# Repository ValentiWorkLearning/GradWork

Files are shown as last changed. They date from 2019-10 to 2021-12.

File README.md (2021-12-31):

# GradWork


Development board for smart-handwatch based on NRF52832 E73 module with C++20/CMake/VSCode based development flow

* Uses the C++20 features as wide as possible
* Uses С++20 coroutines for non-blocking interactions
* Port of LVGL 8.0 library for ST7789V/GC9A01 display and NRFSDK
* Simulator for fimware development without target MCU
* CI for Windows Simulator build and GCC build for target

### Article:
[C++20 Coroutines on NRF52832 with GTest](https://habr.com/ru/post/566070/)

### Revision v1.2
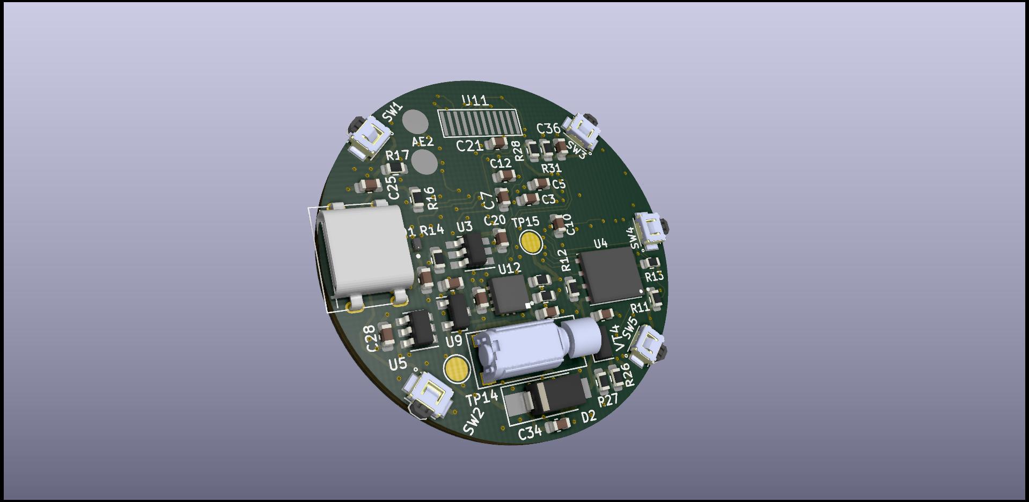
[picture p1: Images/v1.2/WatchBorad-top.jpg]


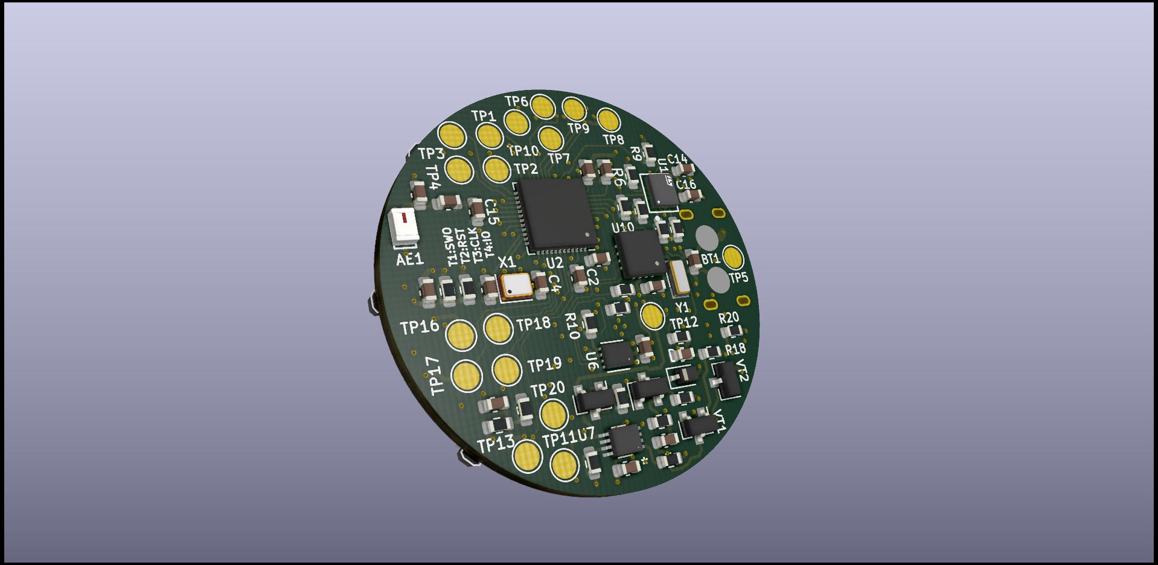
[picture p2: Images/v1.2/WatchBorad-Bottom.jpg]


### Revision v1.0
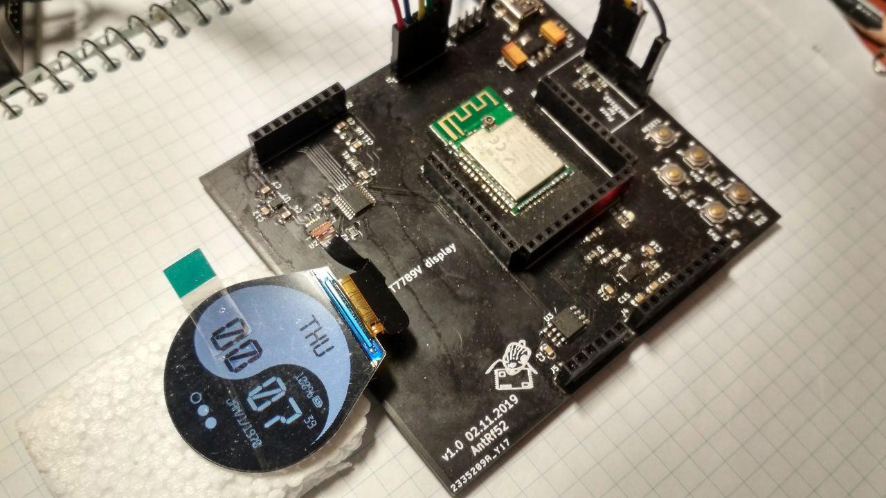
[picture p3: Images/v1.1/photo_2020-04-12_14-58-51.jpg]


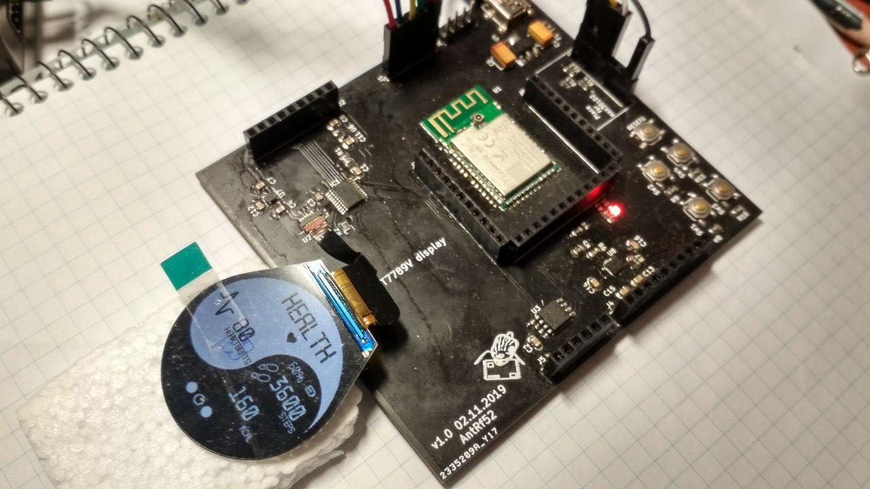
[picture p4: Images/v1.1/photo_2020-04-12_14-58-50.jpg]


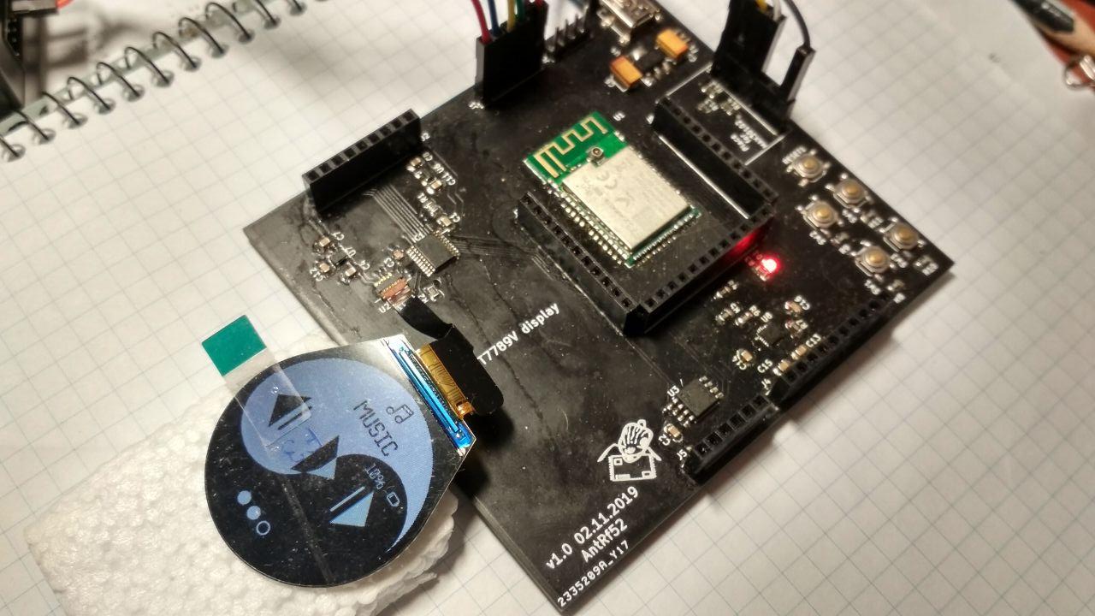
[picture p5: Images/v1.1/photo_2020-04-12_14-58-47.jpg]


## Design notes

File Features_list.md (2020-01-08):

## **Round watch development board  summary **

###### Hardware features:

- [ ] Pulse and SPO2 measuring

- [x] Integration with ST7789V display driver

- [x] LVGL library porting

- [x] BLE custom service

- [ ] Time displaying ( RTC )

- [ ] Time synchronization over BLE Service

- [x] Battery level displaying BLE

- [ ] Battery level displaying Display

- [ ] Accelerometer clock sleep out

- [ ] Energy-Save mode

  ###### Android integration:

- [ ] Alarms support

- [ ] Notifications from Android device

- [ ] Music switching over Android device

  ###### Optional / Additional features

- [ ] Simple 3D render engine for triangles wireframe rendering

- [ ] Mobile application

- [x] CMake-based  build for project

- [x] VSCode debug & development

- [x] KiCad as CAD system for PCB

- [ ] I2S micro for audiomessages

- [ ] Research lightweight inter-processor communication

## **Part list:**

### **MCU:**

NRF52832-E73 module

#### **Accelerometer:**

MPU9250

#### Display module:

ST7789V Round, resolution 240 * 240 or 240 * 208

https://github.com/ValentiWorkLearning/ST7789_Round_DevBoard/tree/master/Panel

https://ru.aliexpress.com/item/1962405888.html?spm=a2g0o.cart.0.0.38713c00M67wvz&mp=1

#### PulseOximeter:

MAX30102/MAX30100

http://www.kosmodrom.com.ua/el.php?name=MAX30100-MODUL

#### **Logic converter:**

TX0108E

http://www.kosmodrom.com.ua/el.php?name=TXS0108EPWR

**Battery controller:**

LTC4054ES5-4.2

http://www.kosmodrom.com.ua/el.php?name=LTC4054ES5-4.2

**LDO**

1. 1.8V - MCP1700T-1802 http://www.kosmodrom.com.ua/el.php?name=MCP1700T-1802E_MB
2. 3.3V - MCP1700T-3302 http://www.kosmodrom.com.ua/el.php?name=MCP1700T-3302E_TT
3. 2.8V - LP2985 http://www.kosmodrom.com.ua/el.php?name=LP2985AIM5-2.8_NOPB

#### Schematic Libraries:

- Nordic nRF52832 MOD

https://kicad.github.io/symbols/RF_Module

- W25Q128

[https://www.snapeda.com/parts/W25Q16BVSSIG/Winbond%20Electronics/view-part/](https://www.snapeda.com/parts/W25Q16BVSSIG/Winbond Electronics/view-part/) 

- MPU-9250

[https://www.snapeda.com/parts/MPU-9250/TDK%20InvenSense/view-part/](https://www.snapeda.com/parts/MPU-9250/TDK InvenSense/view-part/)

#### Software dependencies:

* LVGL - https://github.com/littlevgl/lvgl - open-source embedded GUI library
* Callback connector - library for wrapping C++ class members into C-style callback 

https://github.com/Toxa-man/CallbackConnector 

* Lightweight C++ signals for small systems  https://github.com/larspensjo/SimpleSignal
* SDL-mirror - is used by Simulator subproject https://github.com/spurious/SDL-mirror

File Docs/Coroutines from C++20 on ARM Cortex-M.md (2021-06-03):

### Coroutines from C++20 on ARM Cortex-M

Подробные пояснения по сопрограммам, их особенностям реализации, преимуществами, примерами использования можно посмотреть в следующем списке статей. Ознакомление с статьями рекомендую в следующем порядке:

https://www.youtube.com/watch?v=Ts-1mWBmTNE - MUST WATCH видео от автора предложения Coroutines в стандарт С++20. Раскрыты детали реализации сопрограмм, бенчмарки в сравнении с "callback hell". Рекомендуется к просмотру в первую очередь.

https://blog.panicsoftware.com/coroutines-introduction/ - тут хорошая начальная теория. Либо, взять за основу следующую статью:

https://luncliff.github.io/posts/Exploring-MSVC-Coroutine.html - тут больше картинок и примеры кода есть под конец статьи

https://blog.panicsoftware.com/your-first-coroutine/ - следующая в цикле статей, для начального понимания происходящего

https://lewissbaker.github.io/2017/09/25/coroutine-theory - базовая теория по сопрограммам, для начала может быть сложной

https://habr.com/ru/company/yandex/blog/420861/ - полезный пример "телепортации" между различными очередями задач

https://habr.com/en/post/348602/ - как использовать сопрограммы из С++20 в связке с boost::asio

 https://habr.com/en/post/493808/ // coroutine code linearizing - Линеаризация кода с использованием сопрограмм. Показаны фрагменты реализации модели Акторов.

https://manybutfinite.com/post/anatomy-of-a-program-in-memory/ 

https://manybutfinite.com/post/journey-to-the-stack/

В свою очередь, было решено попробовать фишки из С++20 в домашнем проекте. Прежде, чем собирать все в реальном проекте -  был сделан отдельный репозиторий https://github.com/ValentiWorkLearning/CoroutineExperiments/ . В репозитории была реализована первая идея- использовать сопрограммы для переписывания драйвера для дисплея, работающего по SPI. 

### Пояснение демонстрационного примера из репозитория CoroutineExperiments

Для реализации "эмуляции" передачи данных по интерфейсу SPI  с использованием DMA необходимо реализовать следующий набор функций:

* Сигнатуру HAL(Hardware Abstraction Layer) подобную доступной в API конкретного вендора.
* Пользовательскую сигнатуру для передачи данных( например, передачи команды на дисплей)
* Функцию инициализации дисплея

API для передачи данных, в большинстве своем, имеют похожий вид-указатель на блок данных + размер передаваемого блока + void* на _pUserData -подобный "контекст". Так-же, имеется функционал для инициализации интерфейса.

В случае Nordic, например, сигнатура функции для инициализации SPI имеет вид:

```cpp
nrfx_err_t nrfx_spim_init(nrfx_spim_t  const * const p_instance,
                          nrfx_spim_config_t const * p_config,
                          nrfx_spim_evt_handler_t    handler,
                          void                     * p_context)
```

где p_context- "контекст" который будет доступен в `nrfx_spim_evt_handler_t    handler` callback-е.

Инициализация интерфейса SPI происходит вызовом nrfx_spim_init:

```cpp
APP_ERROR_CHECK(
    nrfx_spim_init(&m_spiHandle, &spiConfig, spimEventHandler, this));
```

Аргументами которой являются:

* m_spiHandle- структура-дескриптор, которая выглядит следующим образом:

  ```cpp
  typedef struct
  {
      NRF_SPIM_Type * p_reg;        ///< Pointer to a structure with SPIM registers.
      uint8_t         drv_inst_idx; ///< Index of the driver instance. For internal use only.
  } nrfx_spim_t;
  ```

* spiConfig- структура с конфигурацией SPI( скорость, используемые порты, etc). Подробнее фрагмент можно посмотреть [ссылка на листинг в репозитории](https://github.com/ValentiWorkLearning/GradWork/blob/9262f65599d58640db2a972ff668a8b065b6441c/Firmware/drivers/spi/spi_wrapper.cpp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)

* spimEventHandler- callback, вызываемый в момент обработки события на шине SPI, по завершению приема/передачи.

* this- контекст, который будет доступен в обработчике события, в текущей реализации-обрабатывает состояние транзакций на шине.

Callback реализован как:

```cpp
static void spimEventHandler(nrfx_spim_evt_t const* _pEvent,
                             void* _pContext) noexcept {
  Meta::UnuseVar(_pContext);
  if (_pEvent->type == NRFX_SPIM_EVENT_DONE) {
    auto pThis = reinterpret_cast<SpiBus::SpiBackendImpl*>(_pContext);
    pThis->m_pSpiBus->handleEvent(
        SpiBus::TCompletedEvent::TransactionCompleted);
  }
}
```

Передача данных по SPI формируется созданием дескриптора транзакции + инициации передачи данных:

```cpp
nrfx_spim_xfer_desc_t xferDesc = NRFX_SPIM_XFER_TX(_pBuffer, _bufferSize);
nrfx_err_t transmissionError = nrfx_spim_xfer
        &m_spiHandle
    ,   &xferDesc
    ,   0
);
```

В общем случае,  можно объединить вызов в :

```cpp
void sendDataChunk(std::uint8_t* _pData,
                   std::uint16_t _dataSize,
                   void* _pUserContext);
```

При необходимости передачи данных блоком, например-  передачи блока команд инициализации на дисплей в неблокирующем режиме - в традиционном варианте необходимо сформировать очередь на отправку, из которой по прерыванию(событию?) доставать новый блок данных и формировать пакет на отправку.

В коде выглядит примерно как:

```cpp
sendCommand(DisplayReg::SLPOUT);
sendCommand(DisplayReg::COLMOD, 0x55);
sendCommand(DisplayReg::MADCTL, 0x08);
```

Реализацию sendCommand можно посмотреть [тут](https://github.com/ValentiWorkLearning/GradWork/blob/9262f65599d58640db2a972ff668a8b065b6441c/Firmware/drivers/display/inc/display/display_spi_common.hpp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)

Вкратце- помещаем в очередь выполнения SPI - транзакцию с beforeTransaction, transactionAction,afterTransaction.

### CoroutineExperiments implementation

В предыдущем разделе был упомянут "объединенный" вызов для запуска передачи данных. Для эмуляции асинхронной передачи данных реализуем HAL-метод следующий образом:

- P.S. восстановление сопрограммы происходит не в потоке, откуда была инициирована передача данных, если это является проблемой- возможно использовать подход, описанный в [Готовимся к С++20. Coroutines TS на реальном примере](https://habr.com/ru/company/yandex/blog/420861/) или [Асинхронность 2: телепортация сквозь порталы](https://habr.com/ru/company/yandex/blog/240525/)

```cpp
void spiBackendImplTransmit(std::uint8_t* _pBuffer,
                            std::uint16_t _bufferSize,
                            void* _pUserData) {
  std::thread dmaThread = std::thread([_pUserData] {
    using namespace std::chrono_literals;
    std::this_thread::sleep_for(500ms);

    std::cout << "TRANSMIT SOME DATA" << std::endl;
    stdcoro::coroutine_handle<>::from_address(_pUserData).resume();
  });
  dmaThread.detach();
}
```

Пользовательский метод передачи данных реализуем следующим образом

```cpp
auto spiTrasnmitCommandBufferAsync(std::uint8_t* _pBuffer,
                                   std::uint16_t _bufferSize) {
  std::cout << "Toggle GPIO ON" << std::endl;
  struct Awaiter {
    std::uint8_t* pBuffer;
    std::uint16_t bufferSize;

    bool await_ready() const noexcept { return false; }
    void await_resume() const noexcept {
      std::cout << "Toggle GPIO OFF" << std::endl;
    }
    void await_suspend(stdcoro::coroutine_handle<> thisCoroutine) const {
      spiBackendImplTransmit(pBuffer, bufferSize, thisCoroutine.address());
    }
  };

  return Awaiter{.pBuffer = _pBuffer, .bufferSize = _bufferSize};
}
```

`bool await_ready() const noexcept` - возвращает всегда false, т.к. нам гарантированно надо выполнять операцию для получения результата awaitable.

`void await_resume() const noexcept` - момент "восстановления" сопрограммы

`void await_suspend(stdcoro::coroutine_handle<> thisCoroutine) const` - функция, вызываемая в момент приостановки сопрограммы

И получим следующую реализацию функции инициализации дисплея:

```cpp
auto commandBufferFirst = std::array{0x00u, 0x01u, 0x02u, 0x03u};
auto commandBufferSecond = std::array{0x04u, 0x05u, 0x06u, 0x07u, 0x08u};

void initDisplay() {
  co_await spiTrasnmitCommandBufferAsync(
      reinterpret_cast<std::uint8_t*>(commandBufferFirst.data()),
      commandBufferFirst.size());
  co_await spiTrasnmitCommandBufferAsync(
      reinterpret_cast<std::uint8_t*>(commandBufferSecond.data()),
      commandBufferSecond.size());
}
```

Подробный полный пример доступен [Ссылка на репозиторий](https://github.com/ValentiWorkLearning/CoroutineExperiments/)

### Мигаем светодиодом на NRF52832

Имея механизм сопрограмм, и исследовав пример [Exploring MSVC Coroutine](https://luncliff.github.io/posts/Exploring-MSVC-Coroutine.html)

мы можем помигать светодиодом с весьма интересным синтаксисом:

```cpp

void Board::ledToggle() {
  using namespace std::chrono_literals;
  while (true) {
    co_await 300ms;

    LOG_DEBUG_ENDL("LED TIMER EXPIRED");
    bsp_board_led_invert(0);
  }
}

```

Немного освежив в памяти API FreeRTOS - вспоминается следующий фрагмент кода:

```cpp
xTaskCreate(ledBlinkTask, "ledBlinkTask", 128, NULL, 2, NULL);

void ledBlinkTask(void* pvParameters) {
  while (true) {
    vTaskDelay(300 / portTICK_PERIOD_MS);
    bsp_board_led_invert(0);
  }
}
```

Реализация `co_await 300ms` схожа с вышеупомянутой статьей с [Exploring MSVC Coroutine](https://luncliff.github.io/posts/Exploring-MSVC-Coroutine.html), а именно следующая:

```cpp
auto operator co_await(std::chrono::milliseconds _duration) {
  class Awaitable {
   public:
    explicit Awaitable(std::chrono::milliseconds _duration)
        : m_duration{_duration} {}

    bool await_ready() const { return false; }

    void await_suspend(std::coroutine_handle<> _coroLedHandle) {
      ret_code_t errorCode{};
      errorCode =
          app_timer_start(m_ledDriverTimer, APP_TIMER_TICKS(m_duration.count()),
                          _coroLedHandle.address());
      APP_ERROR_CHECK(errorCode);
    }

    void await_resume() { app_timer_stop(m_ledDriverTimer); }

   private:
    std::chrono::milliseconds m_duration;
  };
  return Awaitable{_duration};
}
```

Где на `await_suspend` сопрограммы делается запуск таймера на заданный период(`300ms`),  в обработчике таймера вызывается `coroutine_handle.resume()` , после которого таймер останавливается в `void await_resume()`. 

Полная реализация доступна [Ссылка на репозиторий,watchboard.cpp](https://github.com/ValentiWorkLearning/GradWork/blob/dev/develop/Firmware/drivers/board/watchboard.cpp)

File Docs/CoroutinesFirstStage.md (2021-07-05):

### Practical C++20 coroutines notes for ARM Cortex-M

Появилась идея в домашнем проекте попробовать использовать сопрограммы из С++20 на маленькой железке. В качестве модуля для экспериментов был выбран E73 NRF52832. Из инструментария, который использовался в процессе разработки- arm-gcc-gnu-none-eabi 10.2, MSVC для проверки идей и прогона тестов на Windows-платформе.
Изначально было в планах продемонстрировать на чем-то концепцию и как именно их можно было применять. Была идея адаптирования примера в виде мигания светодиодом, но он был слишком простой. Необходимо было придумать что-то более сложное и более полезное, что ли. Таким образом появилась идея переписать драйвер дисплея и пары фрагментов SPI-FLASH в проекте-долгострое.

Небольшой план, что будет в заметке:

1. Предыстория с транзакциями
2. Как это работает в общих чертах
3. Работаем с SPI интерфейсом
4. Массив команд инициализации
5. Идеи с std::tuple транзакций
6. Реализуем when_all_sequence
7. Как работает Task из cppcoro
8. Как это тестировать?
9. Добавляем параметрические тесты в GTest
10. Добавляем черновой вариант драйвера для SPI-FLASH
11. Добавляем чтение JEDEC ID
12. Добавляем чтение device id
13. Ожидание окончания выполнения сопрограммы

### 0. Перед прочтением
Заметка предполагает базовое знакомство читателя с сопрограммами/их синтаксисом. В силу наличия более подробных статей на тему деталей реализации сопрограмм и их устройства рекомендуются к прочтению следующие материалы:

* [YOUR FIRST COROUTINE,panicsoftware](https://blog.panicsoftware.com/your-first-coroutine/)

Серия статей от автора библиотеки [cppcoro](https://github.com/lewissbaker/cppcoro)
* https://lewissbaker.github.io/2017/09/25/coroutine-theory
* https://lewissbaker.github.io/2017/11/17/understanding-operator-co-await
* https://lewissbaker.github.io/2018/09/05/understanding-the-promise-type
* https://lewissbaker.github.io/2020/05/11/understanding_symmetric_transfer

В заметке изложение материала может показаться непоследовательным. Предложения буду рад увидеть в виде issues или же в комментариях/сообщениях в Telegram.

Что будет рассмотрено:
* драйвер дисплея с использованием сопрограмм, с использованием таблицы инициализации на базе std::tuple и классического варианта на базе массива команд.
* фрагмент драйвера для SPI-FLASH памяти
* написание тестов на драйвер SPI с использованием параметрических тестов в GTest
* Рассмотрение работы и реализация нескольких примитивов из cppcoro библиотеки.

### 1. Предыстория с транзакциями

Изначально идея переписывания с подхода в виде транзакций появилась как только возникла необходимость расширения транзакционности read-транзакциями. Для формирования очереди отправки этот подход был достаточно удобным, но для очереди приема получалось что-то вроде callback-hell подхода.

В общих чертах, транзакционный подход представлял собой следующую идею:
```cpp
template <typename... Args> void sendCommand(std::uint8_t command, Args... commandArgs) noexcept
{
    sendCommand(command);
    sendChunk(static_cast<std::uint8_t>(commandArgs)...);
}

template <typename... Args> void sendChunk(Args... _chunkArgs) noexcept
{
    std::array chunk = {static_cast<std::uint8_t>(_chunkArgs)...};
    Interface::Spi::Transaction chunkTransaction{};

    chunkTransaction.beforeTransaction = [this] { setDcPin(); };

    chunkTransaction.transactionAction = [this, chunkToSend = std::move(chunk)] {
        m_pBusPtr->sendChunk(
            reinterpret_cast<const std::uint8_t*>(chunkToSend.data()), chunkToSend.size());
    };

    chunkTransaction.afterTransaction = [this] { resetDcPin(); };

    m_pBusPtr->addTransaction(std::move(chunkTransaction));
}
```

Т.е. у нас есть некоторое действие до транзакции, сама транзакция и действие, которое будет выполнено после нее. Использование так-же было достаточно удобным:
```cpp
sendCommand(DisplayReg::SLPOUT);
sendCommand(DisplayReg::COLMOD, 0x55);
sendCommand(DisplayReg::MADCTL, 0x08);
sendCommand(DisplayReg::CASET, 0x00, 0, 0, 240);
```
Этот подход достаточно хорошо себя показал в работе. Типовая задача для применения имела следующий вид:

1. Выставить состояние порта D/C для дисплея для выбора типа принимаемых данных (команда или данные);
2. Сформировать DMA- транзакцию;
3. По ее окончанию выполнить следующую отправку, если блок данных был не полностью отправлен;
4. Или вернуть состояние порта D/C в исходное состояние и перейти к обработке следующей транзакции.

Недостатки стали проявляться при попытке реализации драйвера для SPI-FLASH которая должна была быть использована в связке с Little FS. Где-то в тот-же период времени было найдено предложение в стандарт С++20 по сопрограммам, просмотрена серия мотивирующих статей:
* [Готовимся к С++20. Coroutines TS на реальном примере](https://habr.com/ru/company/yandex/blog/420861/)

* [Асинхронность: назад в будущее](https://habr.com/ru/post/201826/)
* [Асинхронность 2: телепортация сквозь порталы](https://habr.com/ru/company/yandex/blog/240525/)
* [Асинхронность 3: Субъекторная модель](https://habr.com/ru/post/340732/)

И было принято решение о переписывании на сопрограммы части существующих драйверов.

### 2. Как это работает в общих чертах
Для разработчиков, которые имели дело с C#/Python/JS не являются чем-то новым ключевые слова `yeild`, `await`,`async`.(Да, они тут приведены в общем варианте, без принадлежности к конкретному языку). В кратце, идея сопрограмм состоит в возможности приостановки функции в любом месте исполнения с последствующим восстановлением ее работы из прерванной точки. Фактически, мы получаем легковесные потоки уровня пользователя, т.е. для переключения сопрограмм нам нет необходимости обращаться к ядру ОС/etc.

В С++20 минимальный пример сопрограммы может быть представлен в виде следущей конструкции:
```cpp
#include <coroutine>
#include <iostream>

struct Awaitable
{
    struct Promise;
    using promise_type = Promise;

    Awaitable(std::coroutine_handle<promise_type> coroHandle) : thisCoroutine{coroHandle}
    {
        std::cout << "Awaitable created\n";
    }
    ~Awaitable()
    {
        std::cout << "Awaitable destroyed\n";
        if (thisCoroutine)
            thisCoroutine.destroy();
    }
    struct Promise
    {
        auto initial_suspend() noexcept
        {
            return std::suspend_always();
        }
        auto final_suspend() noexcept
        {
            return std::suspend_always();
        }
        void unhandled_exception()
        {
            std::terminate();
        }

        Awaitable get_return_object()
        {
            return Awaitable(std::coroutine_handle<promise_type>::from_promise(*this));
        }
        void return_void() noexcept
        {
        }
    };
    bool isFinished()
    {
        if (thisCoroutine)
            return thisCoroutine.done();
        return false;
    }
    void restore()
    {
        if (thisCoroutine && !thisCoroutine.done())
            thisCoroutine.resume();
    }
    std::coroutine_handle<promise_type> thisCoroutine;
};

Awaitable callMe()
{
    std::cout << "Hello ";
    co_await std::suspend_always{};
    std::cout << "World\n";
}
int main()
{
    auto lazyHello = callMe();
    while (!lazyHello.isFinished())
        lazyHello.restore();

    return 0;
}
```
Где полезная нагрузка- ленивый вывод фразы "Hello world".
Попробуем реализовать идею использования, только на примере чего-то реальнее. Например, инициализации и работы с дисплеем. Для интереса, весь обмен должен происходить с использованием DMA микроконтроллера.

### 3. Работа с SPI интерфейсом
 Для работы с SPI интерфейсом необходимо реализовать небольшой набор Awaitable-типов, на которых может быть вызван оператор `co_await`.
Самый простой вариант имеет следующий вид:
```cpp
struct Awaiter
{
    bool resetDcPin = false;
    bool restoreInSpiCtx = false;
    const std::uint8_t* pTransmitBuffer;
    This_t* pBaseDisplay;
    std::uint16_t bufferSize;

    bool await_ready() const noexcept
    {
        // проверяем, есть ли необходимость выполнять приостановку сопрограммы
        const bool isAwaitReady = pTransmitBuffer == nullptr || bufferSize == 0;
        return isAwaitReady;
    }
    void await_resume() const noexcept
    {
        //вызов, который будет совершен при выполнении .resume() у сопрограммы
        if (resetDcPin)
            pBaseDisplay->setDcPin();
    }
    void await_suspend(std::coroutine_handle<> thisCoroutine) const
    {
        //действие на время приостановки сопрограммы. В SPI драйвер передается handle сопрограммы,
        // после чего она приостановлена.
        if (resetDcPin)
            pBaseDisplay->resetDcPin();

        pBaseDisplay->getSpiBus()->transmitBuffer(
            pTransmitBuffer, bufferSize, thisCoroutine.address(), restoreInSpiCtx);
    }
};
```

В свою очередь, на стороне SPI-драйвера по окончании передачи данных выполняется следующий код:
```cpp
void transmitCompleted() noexcept
{
    const bool isAllDmaTransactionsProceeded = m_transmitContext.fullDmaTransactionsCount == 0;
    const bool isAllChunckedTransactionsCompleted =
        m_transmitContext.chunkedTransactionBufSize == 0;

    if (!isAllDmaTransactionsProceeded)
    {
        //Если еще можем передавать транзакции размером с DMA буфер
    }
    else if (!isAllChunckedTransactionsCompleted)
    {
        // Если транзакции меньше размера DMA буфера не переданы
    }
    else
    {
        // В случае, если все DMA транзакции выполнены- проверяем, в каком контексте выполнения
        // должна быть восстановлена сопрограмма.Не забываем, что этот метод вызывается из контекта
        // прерывания и восстановление тяжелой сопрограммы может привести к трудноулавливааемым
        // ошибкам. Тут есть два варианта - либо восстанавливаемся в контекте прерывания, либо
        // передаем обработчик сопрограммы в очередь,которая обрабатывается в главном потоке. Таким
        // образом, сопрограмма будет восстановлена из main-потока.
        if (m_transmitContext.restoreInSpiCtx)
        {
            m_coroHandle.resume();
        }
        else
        {
            CoroUtils::CoroQueueMainLoop::GetInstance().pushToLater(m_coroHandle);
        }
    }
}
```
В целях уменьшения нагрузки на чтение кода- при выполнении `transmitBuffer` выполняется формирование контекста передачи данных в драйвере, после чего выполняется рассчет целого количества DMA транзакций + размер оставшегося буфера, который так-же будет передан.
Далее, по окончанию передачи DMA транзакции выполлняется вызов `transmitCompleted` где выполняется формирование новой посылки или же выполняется восстановление приостановленной сопрограммы в заданном контексте выполнения( в контексте прерывания или же в главном потоке программы).

### 4. Итерация на массиве команд инициализации
Нам будут необходимы несколько всопомогательных функций. Их больше, чем две. но в общем случае представим их так:
```cpp
auto sendCommand(const std::uint8_t* pBuffer, std::size_t bufferSize) noexcept
{
    const std::uint8_t* commandBuf = pBuffer;
    const std::uint8_t* ArgBuf = pBuffer + 1;
    const std::uint16_t ArgsBufferSize = static_cast<std::uint16_t>(bufferSize - 1);

    return CoroUtils::when_all_sequence(
        sendCommandImpl(commandBuf),
        ArgsBufferSize > 0 ? sendChunk(ArgBuf, ArgsBufferSize) : sendChunk(nullptr, 0));
}

auto sendChunk(const std::uint8_t* pBuffer, std::size_t bufferSize) noexcept
{
    return Awaiter{.pTransmitBuffer = pBuffer,
                   .pBaseDisplay = this,
                   .bufferSize = static_cast<std::uint16_t>(bufferSize)};
}
```

Массив для инициализации дисплея представлен следующим образом:
```cpp
namespace DisplayDriver::InitializationCommands
{
// clang-format off
constexpr std::size_t CommandsSize = 328;
constexpr std::size_t CommandsTransactionsCount = 59;
static auto Commands = std::array<std::uint8_t, CommandsSize>
{
    /***Cmd****Argc****delay****argv*****************************/
        0xFE,   0,      0
    ,   0xEF,   0,      0
    ,   0xEB,   1,      0,      0x14

    ,   0xFE,   0,      0
    ,   0xEF,   0,      0
    ,   0xEB,   1,      0,      0x14
    ,   0xFE,   0,      0
    ,   0xEF,   0,      0
    ,   0xEB,   1,      0,      0x14
    .....
}
// clang-format on
} // namespace DisplayDriver::InitializationCommands
```

Собираем в полноценную картину функцию инициализации дисплея. Для каждой команды необходимо выполнить передачу команды + передачу ее аргументов, если они есть + выполнить ожидание N миллисекунд(после команды DISP_ON, например). Т.к. отправлять мы будем с использованием ранее реализованных функций - получаем следующий вид тела функции:
```cpp
void initDisplay() noexcept
{
    TBaseSpiDisplay::resetResetPin();
    Delay::waitFor(100);
    TBaseSpiDisplay::setResetPin();
    size_t CommandCount = InitializationCommands::CommandsTransactionsCount;
    const std::uint8_t* pBuffer = InitializationCommands::Commands.data();
    while (CommandCount--)
    {
        const std::uint8_t* Command = pBuffer++;
        const std::uint8_t NumArgs = *pBuffer++;
        const std::uint8_t Delay = *pBuffer++;

        co_await TBaseSpiDisplay::sendCommandImpl(Command);
        if (NumArgs)
        {
            co_await TBaseSpiDisplay::sendChunk(pBuffer++, NumArgs);
            pBuffer += (NumArgs - 1);
        }
        if (Delay)
            Delay::waitFor(Delay);
    }
    TBaseSpiDisplay::m_displayInitialized.set();
}
```
Что мы получили? Каждый вызов `sendCommandImpl` - ассинхронный "под капотом". При выполнении ` co_await TBaseSpiDisplay::sendCommandImpl` или `co_await TBaseSpiDisplay::sendChunk` - выполняется приостановка функции initDisplay, при этом управление возвращается вызывающей стороне. По окончании процедуры инициализации выполняется установка флага окончания инициализации дисплея.

Как может выглядеть процедура отправки дисплейного буфера? Т.к. в проекте используется библиотека LVGL - фреймбуфер может быть non-screen-sized, т.е. не полностью соответствовать размеру буфера экрана, что позволяет выполнять отрисовку фрагментами.(Иногда может не быть возможности поместить полностью в память буфер дисплея)

Для реализации функции отправки нам необходимо выполнить отправку команд на установку области экрана, в которую будет осуществлена отрисовка, после чего отправить команду на запись в память дисплея и выполнить отправку дисплейного буфера.
Что-же. В синхронном варианте, данный код мог бы иметь вид:
```cpp
void fillRectangle(
    std::uint16_t x,
    std::uint16_t y,
    std::uint16_t width,
    std::uint16_t height,
    TBaseSpiDisplay::TColor* colorToFill) noexcept
{

    const std::uint16_t DisplayHeight = TBaseSpiDisplay::getHeight();
    const std::uint16_t DisplayWidth = TBaseSpiDisplay::getWidth();

    const bool isCoordsValid{!((x >= DisplayWidth) || (y >= DisplayHeight))};
    if (isCoordsValid)
    {
        //Определяем размеры буфера для отправки
        const size_t BytesSizeX = (width - x + 1);
        const size_t BytesSizeY = (height - y + 1);
        const size_t BytesSquare = BytesSizeX * BytesSizeY;
        const size_t TransferBufferSize = (BytesSquare * sizeof(typename TBaseSpiDisplay::TColor));

        //Формируем область экрана для обновления
        setAddrWindow(x, y, width, height);

        static std::uint8_t RamWriteCmd{0x2C};
        // Команда на запись в экранный буфер
        TBaseSpiDisplay::sendCommandImplFast(&RamWriteCmd);

        //Устанавликаем порт Data/Command в режим работы с данными(все что передано в дисплей
        //воспринимается, как данные, а не как команды)
        TBaseSpiDisplay::setDcPin();
        // Отправляем дисплейный буфер
        TBaseSpiDisplay::sendChunk(
            reinterpret_cast<const std::uint8_t*>(colorToFill), TransferBufferSize);
        // Восстанавливаем состояние порта Data/Command
        TBaseSpiDisplay::resetDcPin();
        // Сигнализируем об окончании заполнении области дисплея
        TBaseSpiDisplay::onRectArreaFilled.emitLater();
    }
}
```

А что необходимо изменить, чтобы код стал выполняться ассинхронно? Т.е. выполнили транзакцию по DMA- вернулись в точку приостановки, отправили следующую команду и/или дисплейный буфер и продолжили выполнение?
На фрагменте ниже приведены все изменения, которые необходимо выполнить(пратически все).
```cpp

//Формируем область экрана для обновления
co_await setAddrWindow(x, y, width, height); // <=============== co_await here

static std::uint8_t RamWriteCmd{0x2C};
// Команда на запись в экранный буфер
co_await TBaseSpiDisplay::sendCommandImplFast(&RamWriteCmd); // <=============== co_await here

TBaseSpiDisplay::setDcPin();
// Отправляем дисплейный буфер
co_await TBaseSpiDisplay::sendChunk(
    reinterpret_cast<const std::uint8_t*>(colorToFill),
    TransferBufferSize); // <=============== co_await here

TBaseSpiDisplay::resetDcPin();

TBaseSpiDisplay::onRectArreaFilled.emitLater();

```

Добавлением в трех строках `co_await` мы получили ассинххронный код. Остается только дописать немного примитивов, которые будут нам необходимы, чтобы это все заработало. А именно, реализовать притивы `when_all_sequence` для запуска последовательности и `Task` для вызова `co_await` на возвращаемом результате функции `setAddrWindow`.

### 5. Для любителей посложнее - итерация на std::tuple<CommandDescriptor>
Данная идея была первой. Представляем таблицу команд инициализации диспллея в виде std::tuple который в свою очередь состоял бы из Дескрипторов команд.
Преимущество- нет необходимости указывать количество аргументов у команды. Все, что задано после `DefaultDelay`- будет считаться аргументом команды.

Дескриптор команды был реализован как:
```cpp
template <std::uint8_t... Command> struct CommandDescriptor
{
};

template <std::uint8_t Command, std::uint8_t CommandDelay, std::uint8_t... CommandArgs>
struct CommandDescriptor<Command, CommandDelay, CommandArgs...>
{
    std::uint8_t commandDelay = CommandDelay;
    std::array<std::uint8_t, sizeof...(CommandArgs) + 1> command{Command, CommandArgs...};
};

template <std::uint8_t Command, std::uint8_t CommandDelay>
struct CommandDescriptor<Command, CommandDelay>
{
    std::uint8_t commandDelay = CommandDelay;
    std::array<std::uint8_t, 1> command{Command};
};

template <std::uint8_t Command> struct CommandDescriptor<Command>
{
    std::uint8_t commandDelay = 0;
    std::array<std::uint8_t, 1> command{Command};
};
```
В свою очередь, для создания таблицы команд для инициализации было необходимо их сохранить в tuple. В первой итерации, это выглядело вот так:
```cpp
static std::tuple CommandsArray = {
    CommandDescriptor<0xFE>{},
    CommandDescriptor<0xEF>{},
    CommandDescriptor<0xEB, DefaultDelay, 0x14>{},
    CommandDescriptor<0xFF, DefaultDelay, 0x60, 0x01, 0x04>{},
    CommandDescriptor<0x74, DefaultDelay, 0x10, 0x75, 0x80, 0x00, 0x00, 0x4E, 0x00>{},
    CommandDescriptor<0xC3, DefaultDelay, 0x14, 0xC4, 0x14, 0xC9, 0x25>{},
    CommandDescriptor<0x74, DefaultDelay, 0x10, 0x85, 0x80, 0x00, 0x00, 0x4e, 0x00>{},
    CommandDescriptor<0x29>{}};
```

Как распаковать подобный `std::tuple` дескрипторов?
Можно применить `std::apply`и в нем уже заниматься распаковкой команд для их отправки.
В таком случае, произойдет небольшое видоизменение функции для инициализации дисплея.

```cpp
template <typename Tuple, std::size_t... Indexes>
CoroUtils::VoidTask launchInit(
    Tuple&& commandSequence,
    std::integer_sequence<std::size_t, Indexes...>) noexcept
{
    (co_await CoroUtils::when_all_sequence(sendCommand(
         std::get<Indexes>(commandSequence).command.data(),
         std::get<Indexes>(commandSequence).command.size())),
     ...);
}
```
Перейдем к рассмотрению используемых примитивов, а именно `CoroUtils::when_all_sequence` и `CoroUtils::VoidTask`.

### 6. Реализуем when_all_sequence
Прежде всего- зачем он необходим? В общем случае- когда мы хотим вызвать `co_await` для всех переданных аргументов.

Как было показано в примере выше, у нас есть необходимость распаковать `std::tuple` команд. Или же, мы не хотим писать несколько раз `co_await` друг-за другом. Например, в случае отправки команды установки экранной области, нам необходимо передать координаты по X/Y.Фрагмент отправки имеет вид:
```cpp
static std::array xAxisCommand = std::array{static_cast<std::uint8_t>(0x2a),
                                            static_cast<std::uint8_t>(xa >> 24),
                                            static_cast<std::uint8_t>(xa >> 16),
                                            static_cast<std::uint8_t>(xa >> 8),
                                            static_cast<std::uint8_t>(xa)};
static std::array yAxisCommand = std::array{static_cast<std::uint8_t>(0x2b),
                                            static_cast<std::uint8_t>(ya >> 24),
                                            static_cast<std::uint8_t>(ya >> 16),
                                            static_cast<std::uint8_t>(ya >> 8),
                                            static_cast<std::uint8_t>(ya)};
co_await sendCommand(xAxisCommand.data(), xAxisCommand.size());
co_await sendCommand(yAxisCommand.data(), yAxisCommand.size());
```

Предположим, что два подряд `co_await` это не проблема. Но что делать, если их станет больше? Например, в случае распаковки `std::tuple` с дескрипторами команд нам необходимо вызвать co_await для каждого дескриптора. Получается, для каждого элемента прийдется писать `co_await std::get<N>`? Не порядок.
Для данного варианта можно применить fold-expression из С++17, с помощью которых вызвать `co_await` для каждого переданного аргумента.
При этом, все переданные задачи мы можем сохранить в `std::tuple`.
Приведем реализацию `WhenAllSequence` с комментариями:
```cpp
template <typename... Tasks> struct WhenAllSequence {
  //  Хранилище переданных задач
  std::tuple<Tasks...> m_taskList;

  explicit WhenAllSequence(Tasks &&... tasks) noexcept
      : m_taskList(std::move(tasks)...) {}

  explicit WhenAllSequence(std::tuple<Tasks...> &&tasks) noexcept
      : m_taskList(std::move(tasks)) {}

  bool await_ready() const noexcept {
    //Возвращаем false, т.к. вызов await_suspend долежн быть выполнен. Если
    //вернуть true- приостановка сопрограммы выполнена не будет, тело
    //await_suspend вызвано не будет.
    return false;
  }

  void await_suspend(stdcoro::coroutine_handle<> handle) noexcept {
    // при вызове co_await будет выполнен вызов launchAll, в котором компиляторм
    // для каждого элемента std::tuple был сгенериррован вызов co_await
    co_await launchAll(
        std::make_integer_sequence<std::size_t, sizeof...(Tasks)>{});
    handle.resume();
  }

  template <std::size_t... Indexes>
  VoidTask launchAll(std::integer_sequence<std::size_t, Indexes...>) {
    // Используя fold-expression из C++17 - вызываем co_await для каждого
    // элемента tuple
    (co_await std::get<Indexes>(m_taskList), ...);
  }

  void await_resume() noexcept {}
};

template <typename... Args> auto when_all_sequence(Args &&... args) noexcept {
  // конструируем WhenAllSequence от переданных аргументов, при этом из
  // аргументов формируем tuple.
  return WhenAllSequence{std::make_tuple(std::move(args)...)};
}

} // namespace CoroUtils
```

Таким образом, получаем возможность не дублировать написание `co_await` для последовательно выполняемых сопрограмм. 

В данной реализации у нас появился возвращаемый тип `VoidTask`. Он нам необходим для приостановки выполнения `await_suspend` т.к. в ином случае при выполнении `co_await` для первого из переданных аргументов в `launchAll` будет выполнено возващение на вызывающую сторону, после чего вызов `handle.resume()` что не совсем соотвествует ожидаемому результату. Восстановление ожидающей сопрограммы должно быть выполнено только после окончания работы всех переданных задач.

Рассмотрим реализацию типа `VoidTask`.
Данный тип представляет собой "ленивую" задачу которая не выполняется до момента вызова на ней оператора `co_await`. Изначально задача приостановлена. Рассмотрим небольшой пример ее работы, прежде чем описывать детали реализации.

```cpp

VoidTask lazyTask()
{
    std::cout<<"I was called\n";
    co_return;
}
int main()
{
    auto lazy = lazyTask();

    return 0;
}
```
Если запустить на wandbox - получим следующий вывод:
```
Start
0
Finish
```
Т.е. тело сопрограммы не было выполнено.
Для того, чтобы выполнить тело сопрограммы - необходимо добавить вызов `co_await` и добавить реализацию `promise_type` для сопрограммы, в которой будет выполнен `co_await`:

```cpp
struct Promise
{
    auto initial_suspend() noexcept
    {
        return std::suspend_never{};
    }
    auto final_suspend() noexcept
    {
        return std::suspend_never{};
    }

    void get_return_object()
    {
    }
    void return_void()
    {
    }

    void unhandled_exception()
    {
        while (1)
        {
        }
    }
};

template <typename... Args> struct std::coroutine_traits<void, Args...>
{
    using promise_type = Promise;
};

void taskEval()
{
    auto lazy = lazyTask();
    co_await lazy;
}
int main()
{   
    taskEval();
    return 0;
}
```

Таким образом, мы получили "ленивую" сопрограмму.

### 7. Как работает Task из cppcoro

`VoidTask` будет частичным примером из библиотеки cppcoro, т.к. в ее реализации `VoidTask` это специализация шаблонного класса `Task` вида `Task<void>`. Разберемся, как он устроен и как он работает.

Прежде всего, для сопрограммы необходимо реализовать `promise_type`.  В нашем случае, т.к. сопрограмма приостанавливает свое выполнение после создания- у `promise_type` вызов `initial_suspend` должен вернуть `std::suspend_always`. Отметим, что так-же `promise_type` должен реализовать обработку поведения в случае выброса необработанного исключения(в нашем случае можем уйти в `std::terminate`), и определить тип возвращаемого объекта наружу, т.е. реализовать метод `get_return_object`.
```cpp
struct task_promise
    {
        task_promise() noexcept = default;
        void return_void() noexcept
        {
        }
        void unhandled_exception() noexcept
        {
            std::terminate();
        }
        VoidTask get_return_object() noexcept
        {
            return VoidTask{std::coroutine_handle<task_promise>::from_promise(*this)};
        }

        auto initial_suspend() noexcept
        {
            return std::suspend_always{};
        }
    };
```

В свою очередь, VoidTask должен определить у себя оператор `co_await` для возможности его вызова.

`operator co_await` должен вернуть на вызвающую сторону `task_awaitable`, который имеет возможность восстановить выполнение приостановленной сопрограммы и дополнительно установить `continuation`, т.е. сопрограмму, которая будет восстановлена после окончания работы текущей сопрограммы.

```cpp
    struct task_awaitable
    {
        task_awaitable(std::coroutine_handle<promise_type> coroutine) : m_coroutine{coroutine}
        {
        }
        bool await_ready() const noexcept
        {
            return !m_coroutine || m_coroutine.done();
        }
        auto await_suspend(std::coroutine_handle<> awaitingRoutine)
        {
            // Используем symmetric-transfer
            // Подробнее можно ознакомиться:
            // https://lewissbaker.github.io/2020/05/11/understanding_symmetric_transfer

            m_coroutine.promise().set_continuation(awaitingRoutine);
            return m_coroutine;
        }

        void await_resume()
        {
        }

        std::coroutine_handle<promise_type> m_coroutine;
    };
```
Необходимо реализовать у `promise` метод для установки `continuation` и так-же добавить возможность вызова `continuation`.

Реализация установки `continuation` представляет собой метод:
```cpp
void set_continuation(std::coroutine_handle<> continuation)
{
    m_continuation = continuation;
}
```
Для вызова установленного `continuation` необходимо реализовать у promise метод `final_suspend`. В методе `final_suspend` вместо `std::suspend_always/std::suspend_never` можно вернуть пользовательский Awaitable-тип, для которого будет сгенерирован вызов `co_await`.

```cpp
struct final_awaitable
{
    bool await_ready() noexcept
    {
        return false;
    }
    template <typename TPromise>
    auto await_suspend(std::coroutine_handle<TPromise> coroutine) noexcept
    {
        task_promise& promise = coroutine.promise();
        return promise.m_continuation;
    }

    void await_resume() noexcept
    {
    }
};
```

Рассмотрим полную реализацию с комментариями для основных моментов:

```cpp
#include <coroutine>
#include <iostream>

struct VoidTask
{
    struct task_promise;
    using promise_type = task_promise;

    struct task_promise
    {
        task_promise() noexcept = default;
        //Сопрограмма ничего не возвращает. return_void
        void return_void() noexcept
        {
        }
        // При перехвате необработанного исключения - std::terminate
        void unhandled_exception() noexcept
        {
            std::terminate();
        }
        //Возвращаемый на вызывающую сторону объект - VoidTask с переданным в конструктор
        //coroutine_handle
        VoidTask get_return_object() noexcept
        {
            return VoidTask{std::coroutine_handle<task_promise>::from_promise(*this)};
        }

        // Изначально сопрограмма приостановлена
        auto initial_suspend() noexcept
        {
            return std::suspend_always{};
        }

        struct final_awaitable
        {
            bool await_ready() noexcept
            {
                // await_ready - false, вызов тела await_suspend является необходимым
                return false;
            }
            template <typename TPromise>
            auto await_suspend(std::coroutine_handle<TPromise> coroutine) noexcept
            {
                // https://lewissbaker.github.io/2020/05/11/understanding_symmetric_transfer
                task_promise& promise = coroutine.promise();
                return promise.m_continuation;
            }

            void await_resume() noexcept
            {
            }
        };

        void set_continuation(std::coroutine_handle<> continuation)
        {
            m_continuation = continuation;
        }

        auto final_suspend() noexcept
        {
            return final_awaitable{};
        }

        std::coroutine_handle<> m_continuation;
    };

    struct task_awaitable
    {
        task_awaitable(std::coroutine_handle<promise_type> coroutine) : m_coroutine{coroutine}
        {
        }
        bool await_ready() const noexcept
        {
            return !m_coroutine || m_coroutine.done();
        }
        auto await_suspend(std::coroutine_handle<> awaitingRoutine)
        {
            m_coroutine.promise().set_continuation(awaitingRoutine);
            return m_coroutine;
        }

        void await_resume()
        {
        }

        std::coroutine_handle<promise_type> m_coroutine;
    };

    VoidTask(std::coroutine_handle<task_promise> suspendedCoroutine)
        : m_coroutine{suspendedCoroutine}
    {
    }

    ~VoidTask()
    {
        // т.к. мы возвращали для initial_suspend у promise_type std::suspend_always -
        // ответственность за удаление coroutine handle остается на нас.
        if (m_coroutine)
            m_coroutine.destroy();
    }

    bool await_ready() const noexcept
    {
        return !m_coroutine || m_coroutine.done();
    }

    auto operator co_await() noexcept
    {
        return task_awaitable{m_coroutine};
    }

    void await_resume()
    {
    }

    std::coroutine_handle<promise_type> m_coroutine;
};
```

### 8. Как это тестировать?
Реализация SPI-драйвера представляет собой шаблонный класс, в который можно передать backend, который будет использоваться для передачи. Решение было принято с целью повышения тестопригодности модуля. В целом, пользователь работает в основном с несколькими методами:

```cpp
void transmitBuffer(
    const std::uint8_t* pBuffer,
    std::uint16_t pBufferSize,
    void* pUserData,
    bool restoreInSpiCtx) noexcept
{
    // установили coroutine_handle
    m_coroHandle = std::coroutine_handle<>::from_address(pUserData);
    //установили вызов, который будет вызван по окончанию передачи в конкретной реализации SPI
    m_backendImpl.setTransactionCompletedHandler([this] { transmitCompleted(); });

    const size_t TransferBufferSize = pBufferSize;
    const size_t FullDmaTransactionsCount = TransferBufferSize / DmaBufferSize;
    const size_t ChunkedTransactionsBufSize = TransferBufferSize % DmaBufferSize;
    const bool ComputeChunkOffsetWithDma = FullDmaTransactionsCount >= 1;

    // сформировали контекст транзакции
    TransactionContext newContext{.restoreInSpiCtx = restoreInSpiCtx,
                                  .computeChunkOffsetWithDma = ComputeChunkOffsetWithDma,
                                  .pDataToTransmit = pBuffer,
                                  .fullDmaTransactionsCount = FullDmaTransactionsCount,
                                  .chunkedTransactionBufSize = ChunkedTransactionsBufSize,
                                  .completedTransactionsCount = 0};

    m_transmitContext = std::move(newContext);

    // выполнили передачу данных
    if (FullDmaTransactionsCount)
    {
        --m_transmitContext.fullDmaTransactionsCount;
        m_backendImpl.sendChunk(pBuffer, DmaBufferSize);
    }
    else
    {
        m_transmitContext.chunkedTransactionBufSize = 0;
        m_backendImpl.sendChunk(pBuffer, pBufferSize);
    }
}
```

По окончанию передачи данных, в реализации backend вызвается `TransactionCompletedHandler`. Рассмотрим фрагмент реализации для Nordic:
```cpp
template <typename PeripheralInstance> class NordicSpi
{

public:
    using This_t = NordicSpi<PeripheralInstance>;
    NordicSpi() noexcept
    {

        nrfx_spim_config_t spiConfig{};

        // конфигурация SPI пропущена .... //
        //инициализация модуля SPIM. если вместо spimEventHandlerThisOne и this передать nullptr и
        //nullptr - передача будет выполнена без использования EasyDMA, т.е. в блокирующем режиме
        APP_ERROR_CHECK(nrfx_spim_init(
            &SpiInstance::HandleStorage[PeripheralInstance::HandleIdx],
            &spiConfig,
            spimEventHandlerThisOne,
            this));
    }

    void sendChunk(const std::uint8_t* pBuffer, const size_t bufferSize) noexcept
    {
        // формирование дескриптора на передачу данных
        nrfx_spimxfer_desc_t xferDesc = NRFX_SPIMXFER_TX(pBuffer, bufferSize);

        // выполнение транзакции
        nrfx_err_t transmissionError = nrfx_spimxfer(
            &SpiInstance::HandleStorage[PeripheralInstance::HandleIdx], &xferDesc, 0);
        APP_ERROR_CHECK(transmissionError);
    }

    void xferChunk(
        std::span<const std::uint8_t> _transmitArray,
        std::span<std::uint8_t> _receiveArray)
    {
        // формирование transmit-receive транзакции
        nrfx_spimxfer_desc_t xferDesc = NRFX_SPIMXFER_TRX(
            _transmitArray.data(),
            _transmitArray.size(),
            _receiveArray.data(),
            _receiveArray.size());

        nrfx_err_t transmissionError = nrfx_spimxfer(
            &SpiInstance::HandleStorage[PeripheralInstance::HandleIdx], &xferDesc, 0);
        APP_ERROR_CHECK(transmissionError);
    }

    using TTransactionCompletedHandler = std::function<void()>;
    void setTransactionCompletedHandler(const TTransactionCompletedHandler& _handler) noexcept
    {
        m_transactionCompleted = _handler;
    }

private:
    static void spimEventHandlerThisOne(nrfx_spim_evt_t const* _pEvent, void* _pContext) noexcept
    {
        // данный обработчик вызывается по окончании передачи данных при помощи EasyDMA
        if (_pEvent->type == NRFX_SPIM_EVENT_DONE)
        {
            // вызываем ранее установленный callback на драйвере верхнего уровня.
            auto pThis = reinterpret_cast<This_t*>(_pContext);
            pThis->m_transactionCompleted();
        }
    }

public:
    TTransactionCompletedHandler m_transactionCompleted;
};

```

В свою очередь, для тестирования драйвера верхнего уровня необходимо релизовать соответствующий `stub-backend` + реализовать тесты.
Рассматриваемые тестовые сценарии:
* передача блока данных меньше размера DMA буфера
* передача блока данных размером с DMA буфер
* передача нескольких блоков данных размером с DMA буфер
* передача нескольких блоков размером с DMA буфер и неполного блока

### 9. Добавляем параметрические тесты в GTest

Тестирование будем производить с использованием GTest фреймворка. С целью избегания copy-paste для тестов с вышеупомянутыми сценариями- воспользуемся функционалом, позволяющим инстанцировать параметрические тесты.

Для поддержки параметрических тестов в фикстуре необходимо добавить еще однин класс, от которого идет наследование помимо базового `::testing::Test`. Для поддержки параметрических тестов необходимо добавить наследование от `::testing::WithParamInterface`.

В нашем случае это будет `std::tuple` вида:
```cpp
public ::testing::WithParamInterface<std::tuple<std::uint16_t, std::string_view>>
```

Где `std::string_view` будет соответствовать названию теста, а `std::uint16_t` - использоваться для задавания размера тестового буфера данных для отправки.

Реализация stub-backend для SPI драйвера представляет собой хранилище spi-транзакций, которые добавляются при каждом вызове `sendChunk`. После чего, по окончании передачи данных может быть выполнено преобразование из отправленных транзакций в полноценный буфер с целью сравнения данных, которые были поставлены на отправку и данных, которы были переданы в драйвер низкого уровня.

Реализация данных функций представлена ниже:

```cpp
void sendChunk(const std::uint8_t* pBuffer, const size_t bufferSize) noexcept
{
    BusTransactionsTransmit.emplace_back(pBuffer, bufferSize);
    m_completedTransaction();
}

using TDataStream = std::vector<std::byte>;
TDataStream getTransmittedData() const
{
    TDataStream stream;
    std::ranges::for_each(BusTransactionsTransmit, [&stream](const auto& _transaction) {
        const auto& [pArray, blockSize] = _transaction;
        auto arraySpan = std::span{pArray, blockSize};
        std::ranges::transform(arraySpan, std::back_inserter(stream), [](std::uint8_t _dataByte) {
            return std::byte{_dataByte};
        });
    });
    return stream;
}
```
 Для работы с параметрическими тестами необходимо добавить его определение + инстанцирование.
 На данном этапе будет опущена реализация примитива SyncWait, она будет приведена далее. Нам она необходима для ожидания окончания работы сопрограммы.

Определение параметрического теста будет иметь вид:

```cpp
TEST_P(SpiDriverTest, CheckRandomSequenceWithLengthTransmissionCorrect)
{
    // получаем размер последовательности
    const std::uint16_t TransactionLength{std::get<0>(GetParam())};
    TDataStream ExpectedStream{TransactionLength};

    std::random_device randomDevice;
    std::mt19937 generator(randomDevice());
    std::uniform_int_distribution<> distribution(0x00, 0xFF);
    // формируем случайную посылку
    std::ranges::generate(ExpectedStream, [&distribution, generator]() mutable {
        return std::byte(distribution(generator));
    });

    CoroUtils::syncWait(sendChunk(
        reinterpret_cast<const std::uint8_t*>(ExpectedStream.data()), ExpectedStream.size()));
    // проверяем соответствие данных, которые должны были быть переданы данным, которые были отправлены в spi-backend
    EXPECT_EQ(TransactionsToDataStream(), ExpectedStream);
}

```

Инстанцирование параметрического теста представлено на фрагменте ниже:

```cpp
INSTANTIATE_TEST_SUITE_P(
    SpiDriverTesting,
    SpiDriverTest,
    ::testing::Values(
        std::make_tuple(Null, "Null"),
        std::make_tuple(SmallerThanSingleDmaTransaction, "SmallerThanSingleDmaTransaction"),
        std::make_tuple(EqualsToSingleDmaTransaction, "EqualsToSingleDmaTransaction"),
        std::make_tuple(ThreeDmaTransactions, "ThreeDmaTransactions"),
        std::make_tuple(SingleDmaAndChunk, "SingleDmaAndChunk"),
        std::make_tuple(ThreeDmaAndChunk, "ThreeDmaAndChunk"),
        std::make_tuple(StressChunked, "StressChunked")),
    [](const auto& testParam) {
        const auto& suiteName = std::get<1>(testParam.param);
        return std::string(suiteName.data());
    });
```

Переданная лямбда позволяет отформатировать название теста, который выполняется.

### 10. Добавляем черновой вариант драйвера для SPI-FLASH
Рассмотрим добавление драйвера для SPI-FLASH памяти. На первом этапе, рассмотрм получение JEDEC ID и device ID. Условия те-же самые, использовать DMA, ассинхронно, не блокироваться на ожидании событий.

Результат, который мы хотим получить, выглядит следующим образом:
```cpp
void Board::initBoardSpiFlash() noexcept
{
    m_pFlashDriver = std::make_unique<Hal::TFlashDriver>();
    if (m_pFlashDriver)
    {
        const std::uint32_t JedecId = co_await m_pFlashDriver->requestJEDEDCId();
        LOG_DEBUG("Jedec Id is:");
        LOG_DEBUG_ENDL(fmt::format("{:#04x}", JedecId));

        const std::span<std::uint8_t> DeviceId = co_await m_pFlashDriver->requestDeviceId();
        LOG_DEBUG_ENDL(fmt::format("{:02X}", fmt::join(DeviceId, "")));
    }
}
```
Для этого нам необходимо реализовать примитив, с помощью которого мы сможем вернуть значение на вызвающую сторону. Рассмотрим расширенный интерфейс `Task`, а именно необходимые измненения для добавления поддержки возврата значения.
1. Необходимо изменить тип `await_resume` у `task_awaitable`:
```cpp
decltype(auto) await_resume()
{
    return m_coroutine.promise().result();
}
```
2. Добавить метод `.result()` у `promise`:
```cpp
TResult& result()
{
    return m_coroutineResult;
}
```
3. Добавить у `promise` метод `return_value`:
```cpp
void return_value(const TResult& _value)noexcept
{
    m_coroutineResult = _value;
}
```
4. Сделать `Task` шаблонным:
```cpp
template <typename TResult> struct Task
```
5. Добавить member в `promise` для сохранения результата.

Полная реализация измененного `Promise`:
```cpp
struct ResultTaskPromise
{
    ResultTaskPromise() noexcept = default;

    void unhandled_exception() noexcept
    {
        std::terminate();
    }
    Task<TResult> get_return_object() noexcept
    {
        // Изменили тип возвращаемого объекта, теперь это шаблонный Task<Result>
        return Task<TResult>{std::coroutine_handle<ResultTaskPromise>::from_promise(*this)};
    }
    auto initial_suspend() noexcept
    {
        return std::suspend_always{};
    }

    void return_value(const TResult& _value) noexcept
    {
        // добавили метод return value
        m_coroutineResult = _value;
    }

    void set_continuation(std::coroutine_handle<> continuation)
    {
        m_continuation = continuation;
    }

    TResult& result()
    {
        // добавили метод result для возвращения результата
        return m_coroutineResult;
    }

    struct final_awaitable
    {
        bool await_ready() noexcept
        {
            return false;
        }
        template <typename TPromise>
        void await_suspend(std::coroutine_handle<TPromise> coroutine) noexcept
        {
            ResultTaskPromise& promise = coroutine.promise();
            if (promise.m_continuation)
            {
                promise.m_continuation.resume();
            }
        }

        void await_resume() noexcept
        {
        }
    };

    auto final_suspend() noexcept
    {
        return final_awaitable{};
    }

    // добавили поле класса для хранения результата
    TResult m_coroutineResult;
    std::coroutine_handle<> m_continuation;
};
```

### 11. Добавляем чтение JEDEC ID
Для чтения JEDEC ID, который представляет собой std::uint32 необходимо добавить в API spi-flash драйвера метод `requestJedecId`:
```cpp
CoroUtils::Task<std::uint32_t> requestJEDEDCId() noexcept
{
    auto receivedData = co_await prepareXferTransaction(
        std::forward_as_tuple(WindbondCommandSet::ReadJedecId),
        WindbondCommandSet::DummyByte,
        WindbondCommandSet::DummyByte,
        WindbondCommandSet::DummyByte);

    std::uint32_t JedecDeviceId{};
    for (std::size_t i{}; i < WindbondCommandSet::JedecIdLength; ++i)
    {
        JedecDeviceId |= (receivedData[i] << (16 - i * 8));
    }

    co_return JedecDeviceId;
}
```

Идея с `std::forward_as_tuple` следующая - все что передано в аргументах -  в функции `prepareXferTransaction` будет рассмотрено как команда + количество dummy-bytes которые нужны для принятия команды. Все что после `forward_as_tuple` - количество dummy-bytes для вычитки данных.

Реализация функции `prepareXferTransaction` следующая: получаем на вход команду в виде tuple + количество пустых посылок. Далее, заполняем передащий буфер сначала командой и ее аргументами, передаем, после- пустыми посылками. Для возвращаемого значения возвращаем slice на буфер с принятыми данными

Реализация функции имеет вид:

```cpp
    template <typename TCommand, typename... Args>
    CoroUtils::Task<std::span<std::uint8_t>> prepareXferTransaction(
        TCommand&& command,
        Args&&... argList)
    {
        auto& transmitBuffer = getSpiBus()->getDmaBufferTransmit();
        auto& receiveBuffer = getSpiBus()->getDmaBufferReceive();

        getSpiBus()->setCsPinLow();

        processTransmitBuffer(transmitBuffer, std::forward<TCommand&&>(command));

        constexpr std::size_t CommandSize = std::tuple_size_v<TCommand>;

        co_await transmitChunk(std::span(transmitBuffer.data(), CommandSize));

        constexpr std::size_t DummyListSize = sizeof...(argList);

        processTransmitBuffer(transmitBuffer, std::forward_as_tuple(argList...));

        auto receivedBlockSpan = co_await xferTransaction(
            std::span(transmitBuffer.data(), DummyListSize),
            std::span(receiveBuffer.data(), DummyListSize));

        getSpiBus()->setCsPinHigh();
        co_return std::span(receiveBuffer.data(), DummyListSize);
    }
```

Где `xferTransaction` представлена в виде:
```cpp
    CoroUtils::Task<std::span<std::uint8_t>> xferTransaction(
        std::span<const std::uint8_t> pTransmitCommand,
        std::span<std::uint8_t> pReceiveBuffer) noexcept
    {
        co_await xferChunk(pTransmitCommand, pReceiveBuffer);
        co_return std::span(pReceiveBuffer.data(), pReceiveBuffer.size());
    }

    template <
        typename TTRansmitBuffer,
        typename TArgsTuple,
        typename Indexes = std::make_index_sequence<std::tuple_size_v<TArgsTuple>>>
    void processTransmitBuffer(TTRansmitBuffer&& transmitBuffer, TArgsTuple&& argsTuple)
    {
        processTransmitBufferImpl(
            std::forward<TTRansmitBuffer&&>(transmitBuffer),
            std::forward<TArgsTuple&&>(argsTuple),
            Indexes{});
    }

    template <typename TTRansmitBuffer, typename TArgsTuple, std::size_t... Index>
    void processTransmitBufferImpl(
        TTRansmitBuffer&& transmitBuffer,
        TArgsTuple&& argsTuple,
        std::index_sequence<Index...>)
    {
        ((transmitBuffer[Index] = std::get<Index>(argsTuple)), ...);
    }
```
### 12. Добавляем чтение device id
Для поддержки чтения device-id необходимо добавить в API драйвера следующую функцию:
```cpp
CoroUtils::Task<std::span<std::uint8_t>> requestDeviceId() noexcept
{
    auto receivedData = co_await prepareXferTransaction(
        std::forward_as_tuple(
            WindbondCommandSet::ReadUniqueId,
            WindbondCommandSet::DummyByte,
            WindbondCommandSet::DummyByte,
            WindbondCommandSet::DummyByte,
            WindbondCommandSet::DummyByte),

        WindbondCommandSet::DummyByte,
        WindbondCommandSet::DummyByte,
        WindbondCommandSet::DummyByte,
        WindbondCommandSet::DummyByte,
        WindbondCommandSet::DummyByte,
        WindbondCommandSet::DummyByte);
    co_return std::span(receivedData.data(), receivedData.size());
}
```
На сторону пользователя, в данном случае вернется slice на принимающий DMA-буфер SPI. А далее его можно отформатировать с использованием `fmtlib` или же `std::format`, в зависимости от поддерживаемого компилятора. 

### 13. Ожидание окончания выполнения сопрограммы

Иногда может возникнуть необходимость подождать выполнения сопрограммы, т.е. заблокировать выполнение текущего потока до момента, пока не будет завершена сопрограмма. Для этого можно реализовать примитив SyncWait.

Рассмотрим построение этого примитива( в cppcoro он так-же реализован, данный параграф скорее рассмотрение того, как он работает)

Мы хотим получить интерфейс вида:
```cpp
TEST_F(FlashDriverTest, RequestJedecId)
{
    auto jedecId = CoroUtils::syncWait(flashDriver.requestJEDEDCId());
    constexpr std::uint32_t MagicTrashFromRawMemory = 13487565; //  For fun;
    EXPECT_EQ(jedecId, MagicTrashFromRawMemory);
}
```
Т.е. по вызову `CoroUtils::syncWait` заблокироваться до получения результата.

1. Реализуем `syncWait`
необходимо получить тип возвращаемого значения из сопрограммы. Для этого необходимо написать небольшую обертку, которая позволит это выполнить. В нашем случае, возвращаемые типы представляют собой Awaitable-примтивы с доступным `operator co_await`.

Примерный интерфейс `syncWait`:
```cpp
template <typename TCoroutine>
auto syncWait(TCoroutine&& _coroutineTask)->//Необходимо получить возвращаемый тип
```
Для получения возвращаемого типа реализуем структуру `AwaitResultGetter`:
```cpp
template <typename TAwaiter> auto awaiterGetter(TAwaiter&& _awaiter)
{
    return static_cast<TAwaiter&&>(_awaiter).operator co_await();
}

template <typename TAwaitable> struct AwaitResultGetter
{
    using Type = decltype(awaiterGetter(std::declval<TAwaitable>()));
    using Result = decltype(std::declval<Type>().await_resume());
};
```
Где возвращаемый тип может быть получен с помощью вызова `.await_resume` на результате `declval` от awaitable-типа

Вызов `makeSyncWaitTask` представляет собой последовательность вызовов `co_yield co_await`:
```cpp
template <typename TAwaitable, typename TTaskResult = AwaitResultGetter<TAwaitable>::Result>
SyncWaitTask<TTaskResult> makeSyncWaitTask(TAwaitable&& awaitable)
{
    co_yield co_await awaitable;
}
```
Где `co_await` приостанавливает текущий вызов, а `co_yield` используется для сохранения результата выполненной сопрограммы.

При этом, необходимо учесть, что при вызове `SyncWait` на VoidTask у нас возвращаемого результата не будет. Проще всего это реализовать через специализацию шаблона для `Promise`.

Блокирование текущего потока выполнения реализовано за счет установки `BlockingEvent` в котором при вызове `.wait` происходит lock на `condition_wariable` до момента, пока не будет установлен `atomic_bool` флаг:
```cpp
class BlockingEvent
{
public:
    void wait()
    {
        std::unique_lock<std::mutex> lock(mutex);
        condEvent.wait(lock, [this] { return m_isSet.load(std::memory_order_acquire); });
    }

    void set()
    {
        m_isSet.store(true, std::memory_order_release);
        condEvent.notify_all();
    }

private:
    std::atomic_bool m_isSet = false;
    std::mutex mutex;
    std::condition_variable condEvent;
};
```
Фрагмент реализации `SyncWait` для типов с вовращаемым результетом не-void:
```cpp
template<typename TResultType>
struct SyncTaskPromise;

template <typename TResultType>
struct SyncWaitTask
{
    using promise_type = SyncTaskPromise<TResultType>;
    using TResultRef = ResultTypeRefHolder<TResultType>::Type;

    SyncWaitTask(stdcoro::coroutine_handle<SyncTaskPromise<TResultType>> suspendedRoutine)
        : m_suspendedRoutine{suspendedRoutine}
    {
    }
    ~SyncWaitTask()
    {
        if (m_suspendedRoutine)
            m_suspendedRoutine.destroy();
    }

    decltype(auto) result() noexcept
    {
        return m_suspendedRoutine.promise().value();
    }

    void await_resume()
    {
    }

    void start(BlockingEvent& _event)
    {
        m_suspendedRoutine.promise().start(&_event);
    }
    stdcoro::coroutine_handle<SyncTaskPromise<TResultType>> m_suspendedRoutine;
};

template<typename TResultType>
struct SyncTaskPromise
{
    using TResultRef = TResultType&&;

    struct FinalAwaitable
    {
        bool await_ready() noexcept
        {
            return false;
        }
        template <typename TPromise>
        void await_suspend(stdcoro::coroutine_handle<TPromise> coroutine) noexcept
        {
            SyncTaskPromise& promise = coroutine.promise();
            promise.m_event->set();
        }
        void await_resume() noexcept
        {
        }
    };

    auto get_return_object() noexcept
    {
        return SyncWaitTask<TResultType>{ stdcoro::coroutine_handle<SyncTaskPromise<TResultType>>::from_promise(*this) };
    }
    void start(BlockingEvent* _pEvent) noexcept
    {
        m_event = _pEvent;
        stdcoro::coroutine_handle<SyncTaskPromise<TResultType>>::from_promise(*this).resume();
    }
    auto initial_suspend() noexcept
    {
        return std::suspend_always{};
    }

    auto final_suspend() noexcept
    {
        return FinalAwaitable{};
    }

    auto yield_value(TResultRef result) noexcept
    {
        m_value = std::addressof(result);
        return final_suspend();
    }

    decltype(auto) value() noexcept
    {
        return static_cast<TResultRef>(*m_value);
    }

    void return_void() noexcept
    {
    }

    void unhandled_exception()
    {
        std::terminate();
    }

    BlockingEvent* m_event;
    std::remove_reference_t<TResultType>* m_value;
};

template <typename TAwaitable, typename TTaskResult = AwaitResultGetter<TAwaitable>::Result>
SyncWaitTask<TTaskResult> makeSyncWaitTask(TAwaitable&& awaitable)
{
    if constexpr (!std::is_same_v<TTaskResult, void>)
        co_yield co_await awaitable;
    else
        co_await awaitable;
}

```

## Небольшие примеры для экспериментов
Полный пример на котором можно экспериментировать:
https://godbolt.org/z/8YoxPPYsW

Пример с использованием SPI-интерфейса для инициализации дисплея. Можно экспериментировать.
https://wandbox.org/permlink/y6s7UVqLQUBy67xK

## Полезные ссылки и материалы
* https://blog.panicsoftware.com/your-first-coroutine/
* https://lewissbaker.github.io/2017/09/25/coroutine-theory
* https://lewissbaker.github.io/2017/11/17/understanding-operator-co-await
* https://lewissbaker.github.io/2018/09/05/understanding-the-promise-type
* https://lewissbaker.github.io/2020/05/11/understanding_symmetric_transfer
* https://gist.github.com/MattPD/9b55db49537a90545a90447392ad3aeb - собрание ссылок и материалов по сопрограммам(доклады, библиотеки, примеры)
* https://github.com/lewissbaker/cppcoro - библиотека, с которой разбирался в процессе написания заметки
* https://github.com/bbelson2/coro-mc-wwl-code - репозиторий из исследования [C++20 Coroutines on Microcontrollers—What We Learned](https://ieeexplore.ieee.org/abstract/document/8995550)

P.S. В дальнейшем хотелось бы раписать про особенности работы сопрограмм, использование пользовательских аллокаторов для них, применение в связке с библиотеками.
Выражаю благодарность @magras, @shiz01, @Dr_Zlo13 за вычитку материала и помощь в подготовке.
P.S.S. Статья является пробой пера, буду рад увидеть пожелания/примечания/etc.

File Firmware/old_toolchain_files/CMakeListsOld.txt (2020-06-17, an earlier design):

cmake_minimum_required(VERSION 3.12)

project(E73DevBoard CXX ASM)

set (TARGET_NAME E73DevBoardBin)

# define some variables just for this example to determine file locations
set(NRF_PROJECT_NAME ble_app_blinky)
set(NRF_BOARD pca10040)
set(NRF_SOFTDEVICE s132)

# define some convenience variables to point to example project directories
set(NRF_CMAKE_CURRENT_LIST ${CMAKE_CURRENT_LIST_DIR})

set(NRF_PROJECT_PATH ${NRF_CMAKE_CURRENT_LIST}/..)
#set(NRF_PROJECT_PATH ${NRF5_SDK_PATH}/examples/ble_peripheral/${NRF_PROJECT_NAME})

set(NRF_PROJECT_DEVICE_PATH ${NRF_PROJECT_PATH}/sdk_dependent)
#set(NRF_PROJECT_DEVICE_PATH ${NRF_PROJECT_PATH}/${NRF_BOARD}/${NRF_SOFTDEVICE})

# you can specify the location of the linker script if desired instead of using a specific file name
set( NRF5_LINKER_SCRIPT ${NRF_PROJECT_PATH}/sdk_dependent/gcc_nrf52.ld )

nRF5x_setup()

nRF5x_addAppScheduler()
nRF5x_addAppFIFO()
nRF5x_addAppTimer()
nRF5x_addAppUART()
nRF5x_addAppButton()
nRF5x_addBSP(TRUE FALSE FALSE) # without this text size is 11 480, with this - 11 760

nRF5x_addBLEGATT() # with this text size = 11784
nRF5x_addBLEPeerManager() #with this text size is
nRF5x_addAppFDS() # 34312
nRF5x_addSensorSimulator() # still 34312
nRF5x_addBLEServiceDbDiscovery()
nRF5x_addBLEGattQueue()

nRF5x_addBLEService(ble_lbs) #still 34312
nRF5x_addBLEService(ble_bas) # increased to 34332
nRF5x_addBLEService(ble_cts_c)

add_definitions(-DCONFIG_GPIO_AS_PINRESET)

# usually you would include files in this directory here, like so:
#include_directories(.)
list(APPEND SOURCE_FILES main.cpp)

# for example projects we include the example source files
message( "Config include inside:" ${NRF_PROJECT_DEVICE_PATH}/config)
include_directories(${NRF_PROJECT_DEVICE_PATH}/config)
include_directories(${NRF_PROJECT_DEVICE_PATH}/board-pinout)
#list(APPEND SOURCE_FILES ${NRF_PROJECT_PATH}/main.c)

nRF5x_addExecutable(${TARGET_NAME} "${SOURCE_FILES}")

add_subdirectory ("graphics")

set (3RDPARTY_DIR "../../../3rdparty")
add_subdirectory( ${3RDPARTY_DIR} ${CMAKE_BINARY_DIR}/3rdparty )

target_compile_definitions(
    ${TARGET_NAME}
    PRIVATE
    S112
    USE_HARDWARE_DISPLAY_BACKEND
    USE_NRFSDK_SIMULATOR
    USE_BLE_SERVICES
    USE_DEVICE_SPECIFIC
    LoggerSegger
)

target_sources(
    ${TARGET_NAME}
    PRIVATE
    ${CMAKE_CURRENT_LIST_DIR}/drivers/display/display_st7789v.cpp
    ${CMAKE_CURRENT_LIST_DIR}/drivers/spi/spi_wrapper.cpp
    ${CMAKE_CURRENT_LIST_DIR}/drivers/ble/ble_softdevice.cpp
    ${CMAKE_CURRENT_LIST_DIR}/drivers/ble/ble_custom_service.cpp
    ${CMAKE_CURRENT_LIST_DIR}/drivers/ble/ble_battery_service.cpp
    ${CMAKE_CURRENT_LIST_DIR}/drivers/ble/ble_datetime_service.cpp
    ${CMAKE_CURRENT_LIST_DIR}/drivers/factory_impl/ih_ble_service_factory.cpp
    ${CMAKE_CURRENT_LIST_DIR}/drivers/factory_impl/ih_ible_softdevice.cpp
    ${CMAKE_CURRENT_LIST_DIR}/drivers/factory_impl/ih_ble_service_factory.cpp
    ${CMAKE_CURRENT_LIST_DIR}/drivers/winbondflash/winbond_flash.cpp
    ${CMAKE_CURRENT_LIST_DIR}/service_providers/battery/sp_battery_service_fake.cpp # increase to 41960
    ${CMAKE_CURRENT_LIST_DIR}/service_providers/heartrate/sp_heartrate_service_fake.cpp
    ${CMAKE_CURRENT_LIST_DIR}/service_providers/datetime/sp_datetime_service_fake.cpp # increase to 42158
    ${CMAKE_CURRENT_LIST_DIR}/service_providers/sp_fake_services_creator.cpp
    ${CMAKE_CURRENT_LIST_DIR}/logger/logger_service_impl.cpp
    ${CMAKE_CURRENT_LIST_DIR}/ap_application.cpp
)

target_include_directories(
    ${TARGET_NAME}
    PUBLIC
    ${3RDPARTY_DIR}/etl
    ${CMAKE_CURRENT_LIST_DIR}/graphics
    ${CMAKE_CURRENT_LIST_DIR}/drivers
    ${CMAKE_CURRENT_LIST_DIR}/drivers/ih
    ${CMAKE_CURRENT_LIST_DIR}/drivers/ble
    ${CMAKE_CURRENT_LIST_DIR}/utils
    ${CMAKE_CURRENT_LIST_DIR}/logger
    ${CMAKE_CURRENT_LIST_DIR}/service_providers
)

target_link_libraries(
    ${TARGET_NAME}
    etl
    watch_graphics
    lvgl_lib
)

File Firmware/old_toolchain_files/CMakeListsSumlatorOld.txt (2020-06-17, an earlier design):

cmake_minimum_required(VERSION 3.12)

set (TARGET_NAME WatchSim )

project(FirmwareSimulator)

set (CMAKE_LIBRARY_OUTPUT_DIRECTORY ${CMAKE_BINARY_DIR})
set (CMAKE_RUNTIME_OUTPUT_DIRECTORY ${CMAKE_BINARY_DIR})

list(APPEND EXTRA_LIBS vcruntime user32 gdi32 winmm imm32 ole32 oleaut32 version uuid advapi32 setupapi shell32)

add_compile_options(/wd4576)

if (MSVC_VERSION GREATER_EQUAL "1900")
    include(CheckCXXCompilerFlag)
    CHECK_CXX_COMPILER_FLAG("/std:c++latest" _cpp_latest_flag_supported)
    if (_cpp_latest_flag_supported)
        add_compile_options("/std:c++latest")
    else()
        set_target_properties(
            ${TARGET_NAME}
            PROPERTIES
            CXX_STANDARD 17
        )
    endif()
endif()

add_subdirectory ("graphics")
add_subdirectory("graphics/SDL-mirror")

set (FIRMWARE_SRC_DIR "/../Firmware/Firmware/src/")

set (3RDPARTY_DIR "../3rdparty")
add_subdirectory( ${3RDPARTY_DIR} ${CMAKE_BINARY_DIR}/3rdparty )

add_executable(
    ${TARGET_NAME}
    ${CMAKE_CURRENT_LIST_DIR}/${FIRMWARE_SRC_DIR}/drivers/factory_impl/ih_ble_service_factory.cpp
    ${CMAKE_CURRENT_LIST_DIR}/${FIRMWARE_SRC_DIR}/drivers/factory_impl/ih_ible_softdevice.cpp
    ${CMAKE_CURRENT_LIST_DIR}/${FIRMWARE_SRC_DIR}/drivers/factory_impl/ih_ble_service_factory.cpp
    ${CMAKE_CURRENT_LIST_DIR}/${FIRMWARE_SRC_DIR}/drivers/factory_impl/ble_services_stub.cpp
    ${CMAKE_CURRENT_LIST_DIR}/${FIRMWARE_SRC_DIR}/drivers/ble/ble_desktop_softdevice.cpp
    ${CMAKE_CURRENT_LIST_DIR}/${FIRMWARE_SRC_DIR}/service_providers/battery/sp_battery_service_fake.cpp
    ${CMAKE_CURRENT_LIST_DIR}/${FIRMWARE_SRC_DIR}/service_providers/heartrate/sp_heartrate_service_fake.cpp
    ${CMAKE_CURRENT_LIST_DIR}/${FIRMWARE_SRC_DIR}/service_providers/datetime/sp_datetime_service_fake.cpp
    ${CMAKE_CURRENT_LIST_DIR}/${FIRMWARE_SRC_DIR}/service_providers/sp_fake_services_creator.cpp
    ${CMAKE_CURRENT_LIST_DIR}/${FIRMWARE_SRC_DIR}/logger/logger_service_impl.cpp
    ${CMAKE_CURRENT_LIST_DIR}/${FIRMWARE_SRC_DIR}/ap_application.cpp
    ${CMAKE_CURRENT_LIST_DIR}/${FIRMWARE_SRC_DIR}/main.cpp
)

target_compile_definitions(
    ${TARGET_NAME}
    PUBLIC
    SDL_MAIN_HANDLED
    USE_DESKTOP_SIMULATOR
    USE_WINSDL_BACKEND
    LoggerDesktop
    _CRT_SECURE_NO_WARNINGS
)

target_include_directories(
    ${TARGET_NAME}
    PUBLIC
    "graphics/SDL-mirror/include"
    ${3RDPARTY_DIR}/etl
    ${3RDPARTY_DIR}/fmt
    ${Boost_INCLUDE_DIRS}
    ${CMAKE_CURRENT_LIST_DIR}/${FIRMWARE_SRC_DIR}
    ${CMAKE_CURRENT_LIST_DIR}/${FIRMWARE_SRC_DIR}/drivers
    ${CMAKE_CURRENT_LIST_DIR}/${FIRMWARE_SRC_DIR}/drivers/ih
    ${CMAKE_CURRENT_LIST_DIR}/${FIRMWARE_SRC_DIR}/utils
    ${CMAKE_CURRENT_LIST_DIR}/${FIRMWARE_SRC_DIR}/logger
    ${CMAKE_CURRENT_LIST_DIR}/${FIRMWARE_SRC_DIR}/service_providers
)

target_link_libraries(
    ${TARGET_NAME}
    SDL2
    lvgl_lib
    etl
    fmt
)

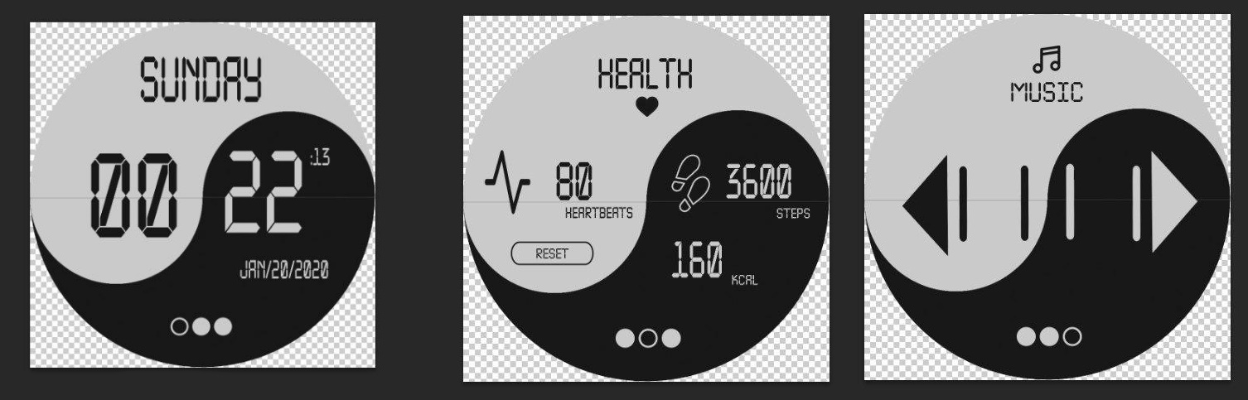
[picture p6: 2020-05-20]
Images/Design/v1.1_Render/HealthPageLightCombined.jpg

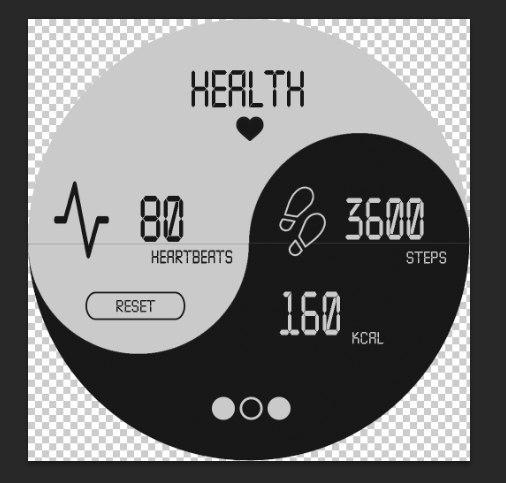
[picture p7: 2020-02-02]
Images/Design/v1.1_Render/HealthPageLight.jpg

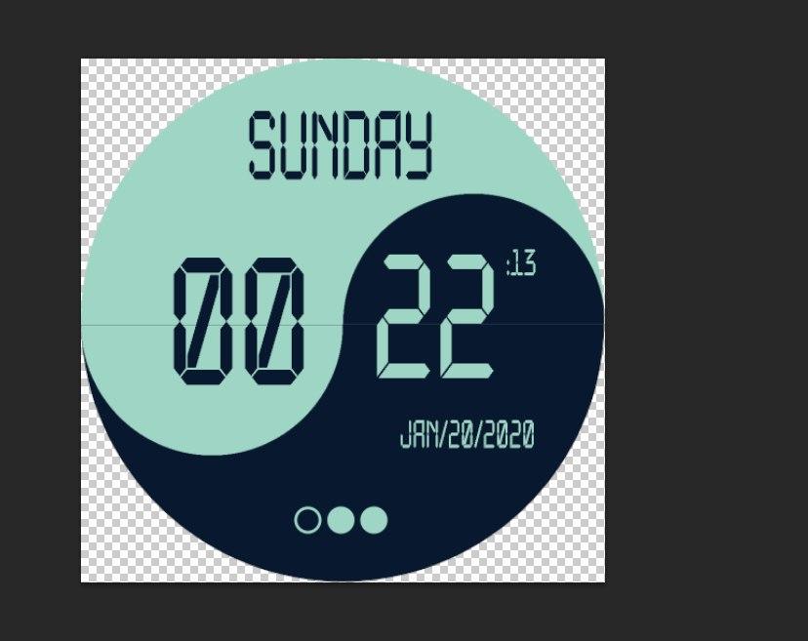
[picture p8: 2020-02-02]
Images/Design/v1.1_Render/MainPage.jpg

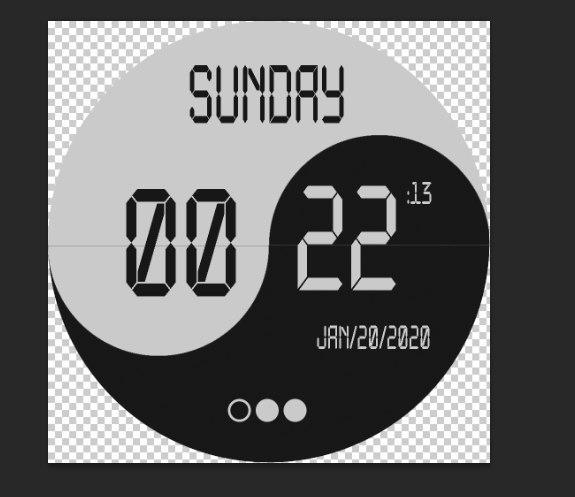
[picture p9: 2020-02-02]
Images/Design/v1.1_Render/MainPageLight.jpg

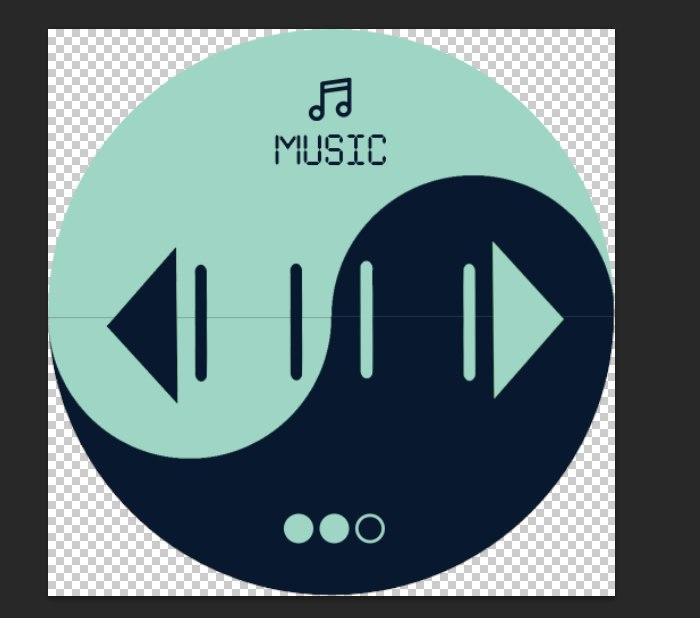
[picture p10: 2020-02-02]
Images/Design/v1.1_Render/MusicPage.jpg

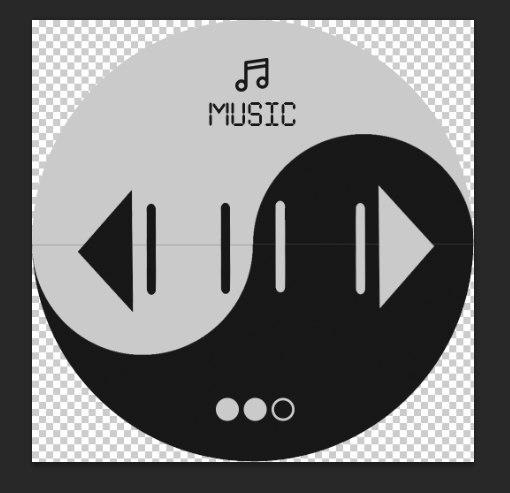
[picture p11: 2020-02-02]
Images/Design/v1.1_Render/MusicPageLight.jpg

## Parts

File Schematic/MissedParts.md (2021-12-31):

1. D_TVS
https://lcsc.com/product-detail/TVS_PN-SILICON-PESDU0521P1_C499647.html
* Replacement: https://lcsc.com/product-detail/TVS_Leiditech-ESDA05CP_C384839.html

2. Schottky Barrier
https://lcsc.com/product-detail/Schottky-Barrier-Diodes-SBD_Shandong-Jingdao-Microelectronics-SS12_C353243.html
* Replacement: https://lcsc.com/product-detail/Schottky-Barrier-Diodes-SBD_Slkor-SLKORMICRO-Elec-SS12_C513476.html

3. Switches
https://lcsc.com/products/Tactile-Switches_427.html?q=b3u-3000
* Replacement: https://lcsc.com/product-detail/Tactile-Switches_Omron-Electronics-B3U-3000P_C963349.html
 
4. BNO055
https://lcsc.com/product-detail/Sensors_Bosch-Sensortec_BNO055_Bosch-Sensortec-BNO055_C93216.html
* Replacement ?
- https://www.digikey.com/en/products/detail/bosch-sensortec/BHI160B/9674245
- https://lcsc.com/product-detail/Motion-Sensors-Accelerometers_Bosch-Sensortec-BHI160B_C464452.html
- https://github.com/BoschSensortec/BMA400-API

5. FLASH Memory:

* Replacement:
https://lcsc.com/product-detail/FLASH_Winbond-Elec-W25Q128JVPIQTR_C190862.html

6. BMS:

https://lcsc.com/product-detail/_STMicroelectronics_STC3100IQT_STC3100IQT_C155587.html

7. Switching controllers:

https://lcsc.com/product-detail/Switching-Controllers_Texas-Instruments_TPS2115APWR_Texas-Instruments-Texas-Instruments-TPS2115APWR_C70287.html

8. Supervisors

https://lcsc.com/product-detail/Microprocessor-Microcontroller-Supervisors_ON-Semiconductor-ON-Semiconductor-MAX809STRG_C9965.html

9. DC-DC Converter

https://lcsc.com/product-detail/DC-DC-Converters_Texas-Instruments_TPS62740DSSR_Texas-Instruments-Texas-Instruments-TPS62740DSSR_C128606.html

10. 32768crystal

https://lcsc.com/product-detail/SMD-Crystal-Resonators_Seiko_SC-20S-32-768kHz-20PPM-7pF_Seiko-SC-20S-32-768kHz-20PPM-7pF_C97602.html

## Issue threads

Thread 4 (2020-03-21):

Adding unit tests

ValentiWorkLearning, 2020-03-21:
The project size is increasing. The unit tests should be added for the following parts, with the first priority:
* Display driver and SPI bus driver
* Date time service interaction and syncronizing via BLE
* Event disptacher

ValentiWorkLearning, 2020-04-20:
Also to
*Main window
*Controllers classes

ValentiWorkLearning, 2020-04-29:
https://github.com/google/googletest/blob/master/googletest/docs/primer.md

ValentiWorkLearning, 2020-04-29:
https://github.com/google/googletest/blob/b8e2562086ef326a4a88089f85b29ce7b6f9464b/googlemock/docs/ForDummies.md

ValentiWorkLearning, 2020-06-22:
https://github.com/google/googletest/blob/master/googlemock/docs/cheat_sheet.md

ValentiWorkLearning, 2020-10-05:
https://github.com/google/googletest/blob/master/googletest/docs/advanced.md

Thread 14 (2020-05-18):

Improve BLE Driver

ValentiWorkLearning, 2020-05-18:
Here are some improvements for BLE driver:

- Add interface for the following BLE services:

- [x]  Battery service
- [x]  DTS service
- [ ]  Pedometer service
- [x]  Heartrate service

- [x] Add simulator for BLE service for Desktop and Nordic platform

ValentiWorkLearning, 2020-05-19:
becf18b3d78622110f2aacc06c500d2ab8a789be

Closed 2020-08-29.

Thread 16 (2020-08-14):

Buttons handling

ValentiWorkLearning, 2020-08-14:
Consider to add buttons handling to the application. The implementations steps are below:

- [x] Implement tests for buttons driver
- [x] Implement Nordic buttons driver handling
- [x] Implement desktop buttons fake driver( or, maybe two implementations for manual and automated buttons event dispatching )
- [x] Implement buttons handling in application. Now, only handling of Next/Previous watch page buttons can be implemented.

ValentiWorkLearning, 2020-08-20:
Implemented buttons handling for the watch firmware. Covered with tests. Tested manually.

Closed 2020-08-20.

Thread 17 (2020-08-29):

Filesystem Implementation

ValentiWorkLearning, 2020-08-29:
The filesystem for storing some useful data (maybe, pictures for different app notifications or schedule of alarms ).

Steps

- [ ] Implement the driver for on-board SPI flash.
[W25Q16BV_Winbond.pdf](https://github.com/ValentiWorkLearning/GradWork/files/5145573/W25Q16BV_Winbond.pdf)
[Driver example ](https://github.com/nimaltd/w25qxx/blob/master/w25qxx.c)

- [ ] Implement concept of the BlockDevice Allocator:
[Mbed Littlefs filesystem class reference ]( https://os.mbed.com/docs/mbed-os/v6.2/apis/littlefilesystem.html)
- [ ] Implement tests for the BlockDevice  Allocator

- [ ] Implement draft of LFS launch using BlockAllocator driver
[LittleFS official repository](https://github.com/ARMmbed/littlefs)
- [ ] Add launch of LFS tests on desktop
- [ ] Implement LFS config with Winbond flash driver
- [ ] Add launch of LFS tests on the target NRF52 board

- [ ] Discover JFlashSPI cmd utility for automated resource deploying on a flash device
- [ ] Automate filesystem pre-init mounting using
[mklfscommandline for creating images of LittleFS on a desktop platform](https://github.com/whitecatboard/Lua-RTOS-ESP32/tree/master/components/mklfs)

ValentiWorkLearning, 2020-08-31:
https://www.cnblogs.com/shangdawei/archive/2013/04/28/3049777.html

ValentiWorkLearning, 2020-09-05:
https://github.com/geky/coru

ValentiWorkLearning, 2021-11-19:
https://github.com/ARMmbed/mbed-os/blob/master/storage/blockdevice/source/HeapBlockDevice.cpp

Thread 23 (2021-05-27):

Support basic coroutines in the architecture

ValentiWorkLearning, 2021-05-27:
For reaching the tasks fulfilment the next list of sub-goals should be reached:

- [x] Implement basic coroutine primitives
- [x] Add spi driver with coroutines support
- [x] Implement the current display driver with coroutines
- [x] Implement SPI-flash reading JEDEC ID and Serial with coroutines instead of transactions

ValentiWorkLearning, 2021-05-27:
[ ] Move old drivers somewhere for further possibility of looking for them.
[ ] Move coroutine examples and thoughts somewhere close to old drivers

Closed 2021-06-03.

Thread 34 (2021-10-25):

Replacement of ASSERT_EQ to EXPECT_EQ

ValentiWorkLearning, 2021-10-25:
https://github.com/ValentiWorkLearning/GradWork/blob/9bc5591664e8210aed27ff22b856637016add023/Firmware/firmware_tests/buttons_driver/buttons_driver_test.cpp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
Accroding to the GTest Premier, the usage of EXPECT_EQ must be preffered over the ASSERT_EQ.

Closed 2021-11-03.

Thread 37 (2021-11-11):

Test firmware implementation

ValentiWorkLearning, 2021-11-11:
Because of the further PCB release it's necessary to provide a set of the testing utilities for debugging.
-[ ] I2C scanner
-[ ] Led driver

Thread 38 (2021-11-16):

Small chematic issues in schematic files

ValentiWorkLearning, 2021-11-16:
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

Closed 2021-11-17.

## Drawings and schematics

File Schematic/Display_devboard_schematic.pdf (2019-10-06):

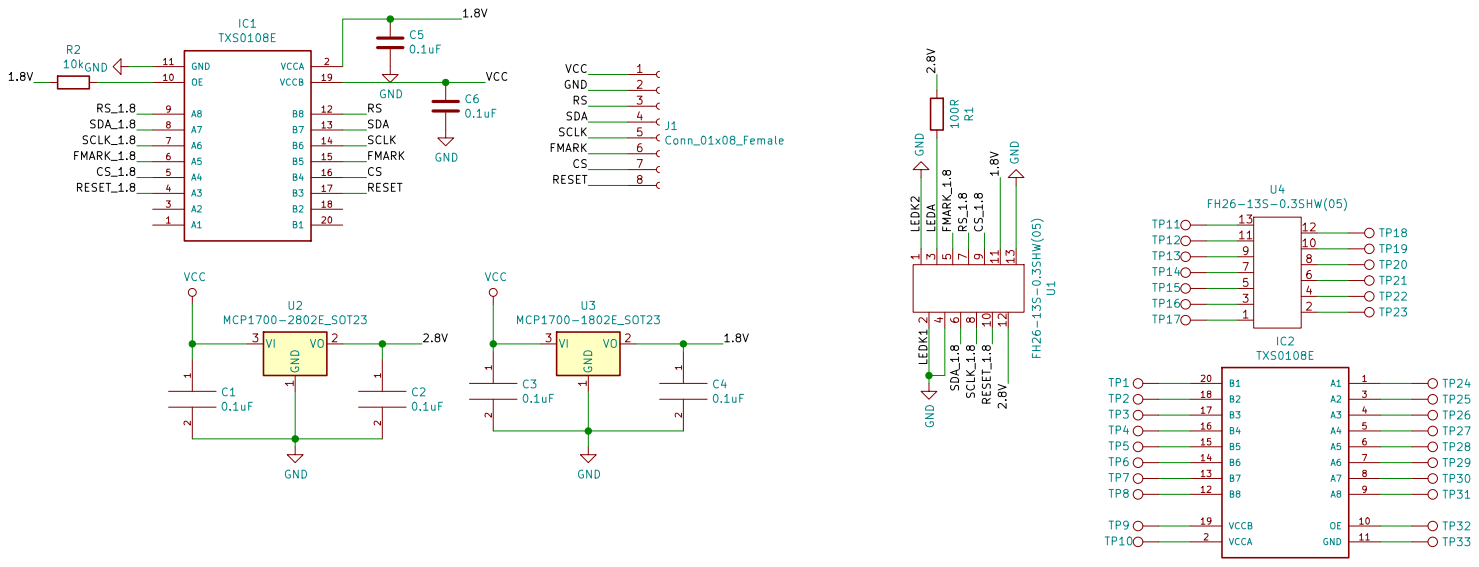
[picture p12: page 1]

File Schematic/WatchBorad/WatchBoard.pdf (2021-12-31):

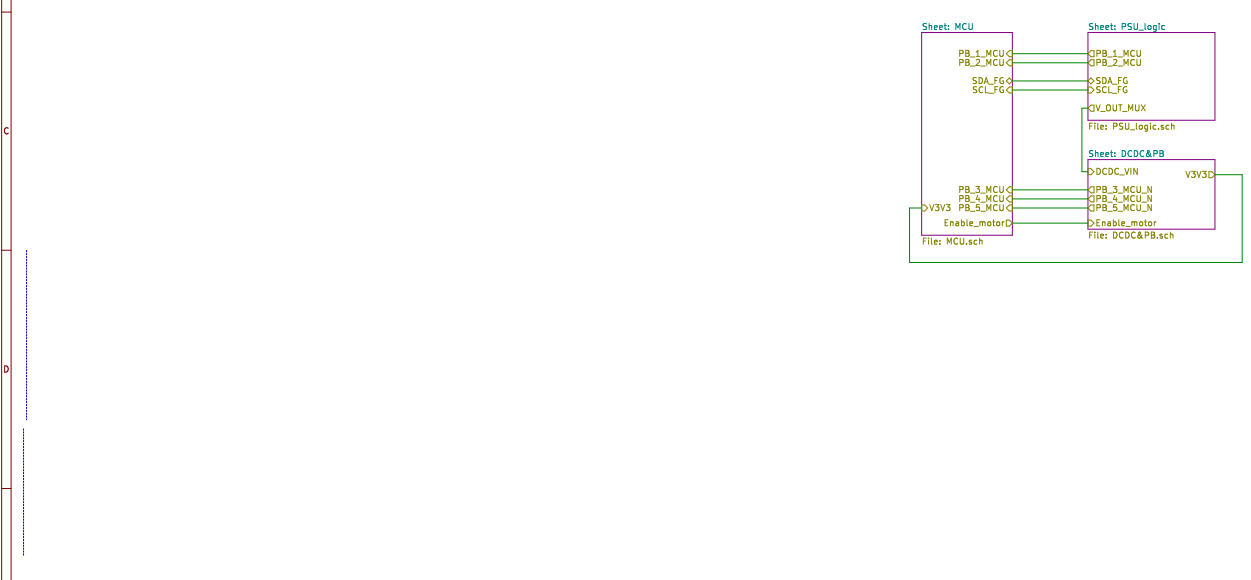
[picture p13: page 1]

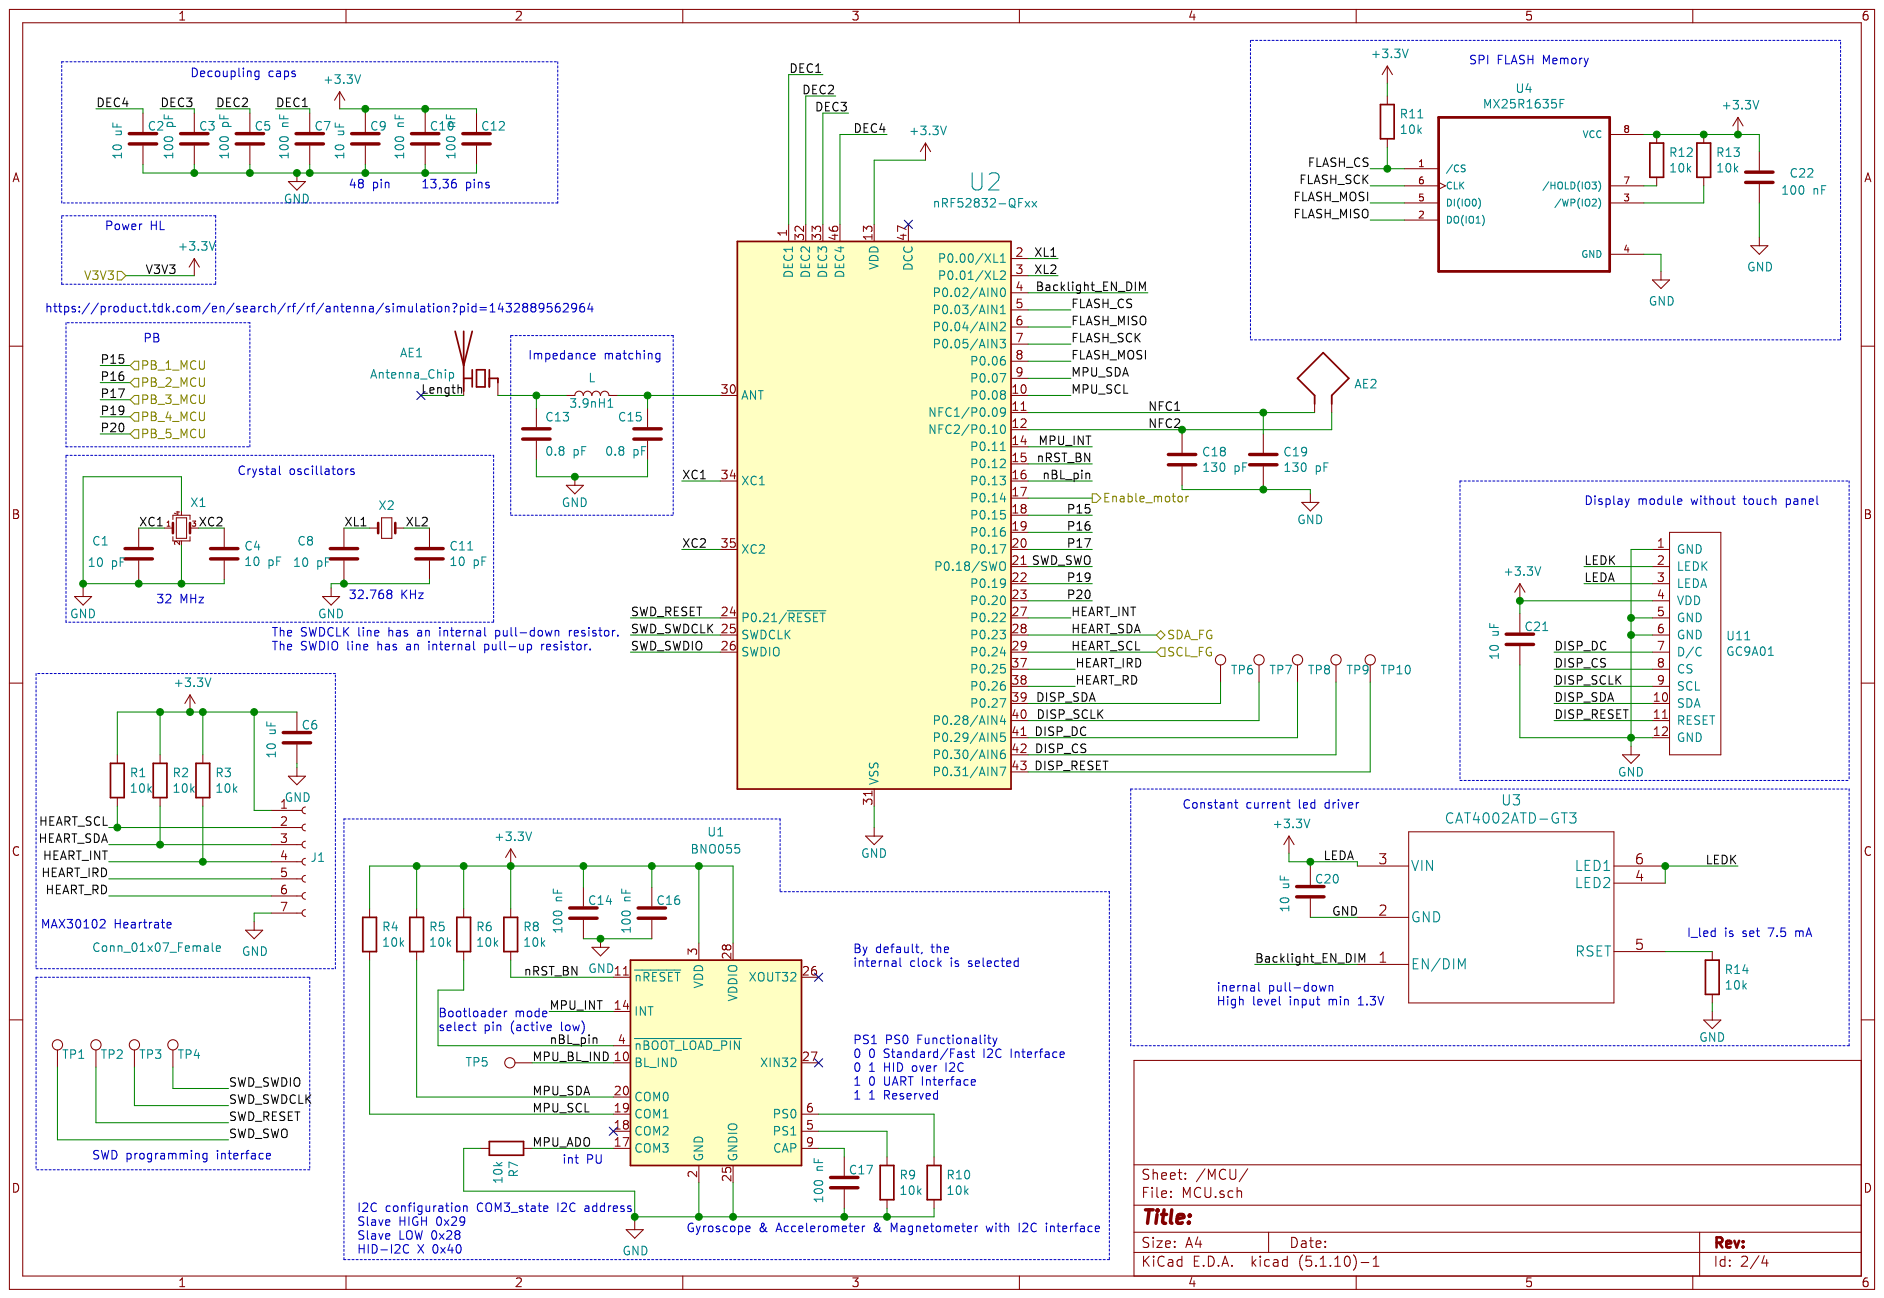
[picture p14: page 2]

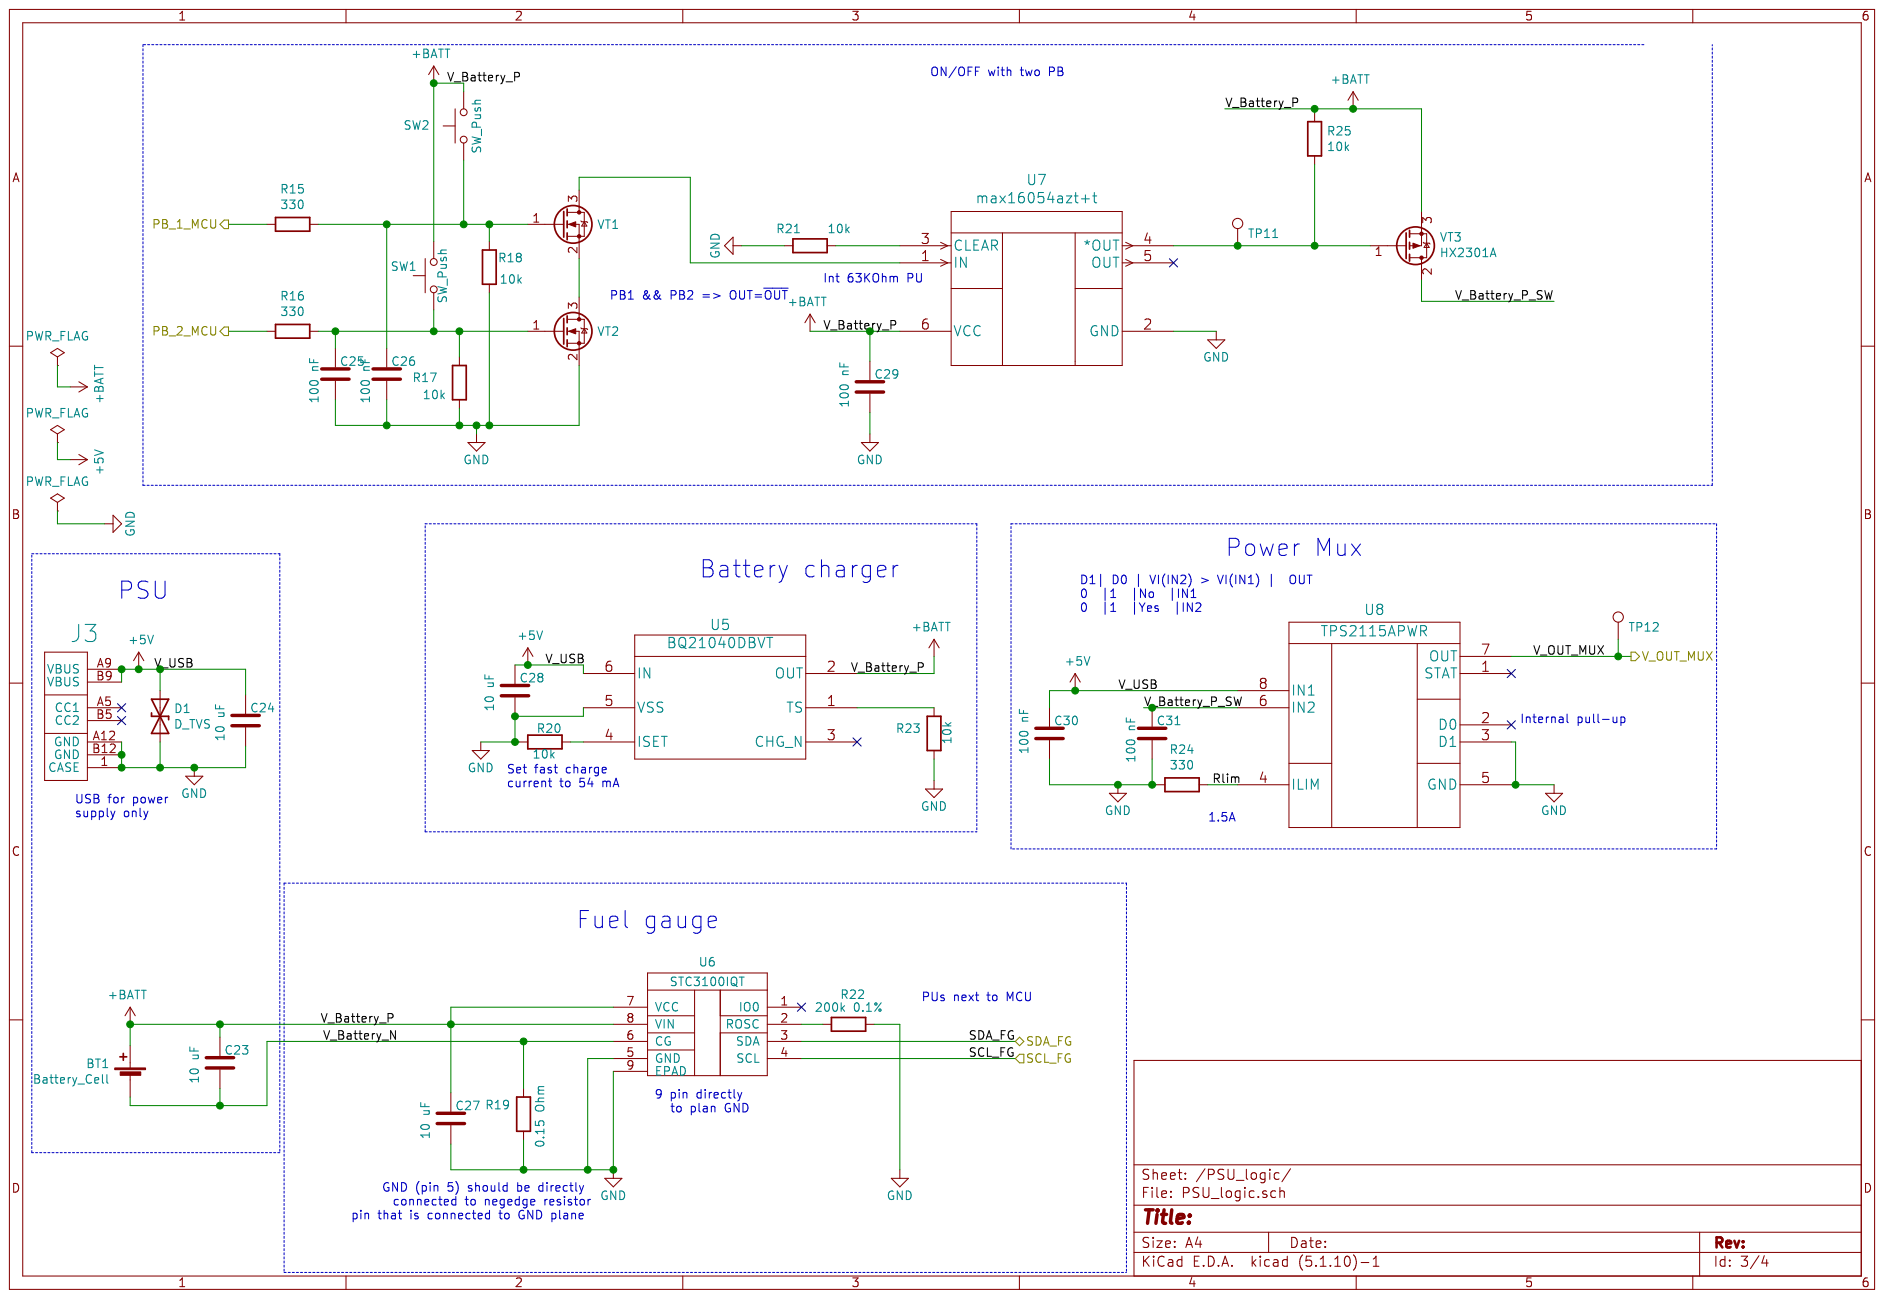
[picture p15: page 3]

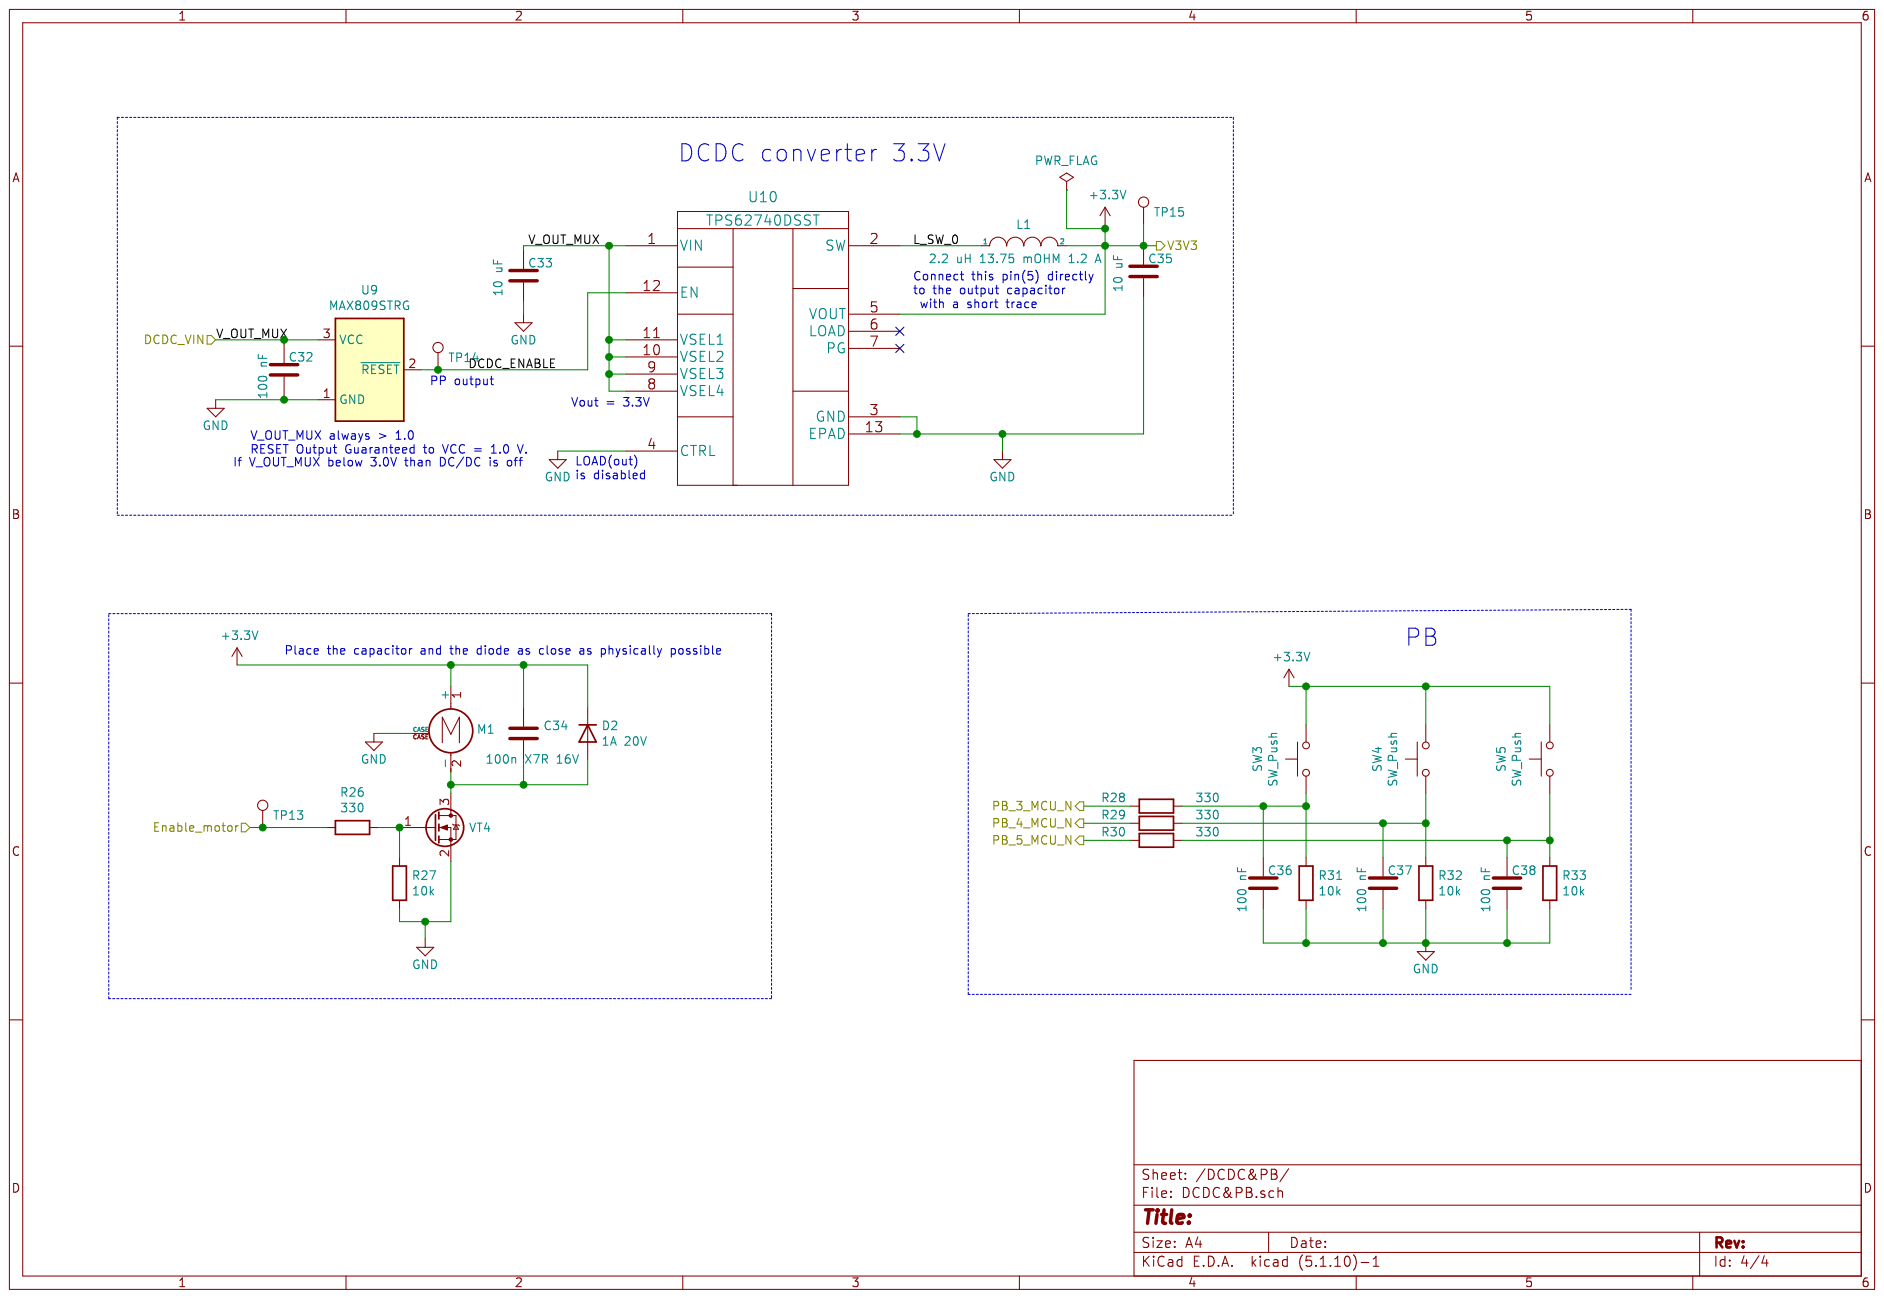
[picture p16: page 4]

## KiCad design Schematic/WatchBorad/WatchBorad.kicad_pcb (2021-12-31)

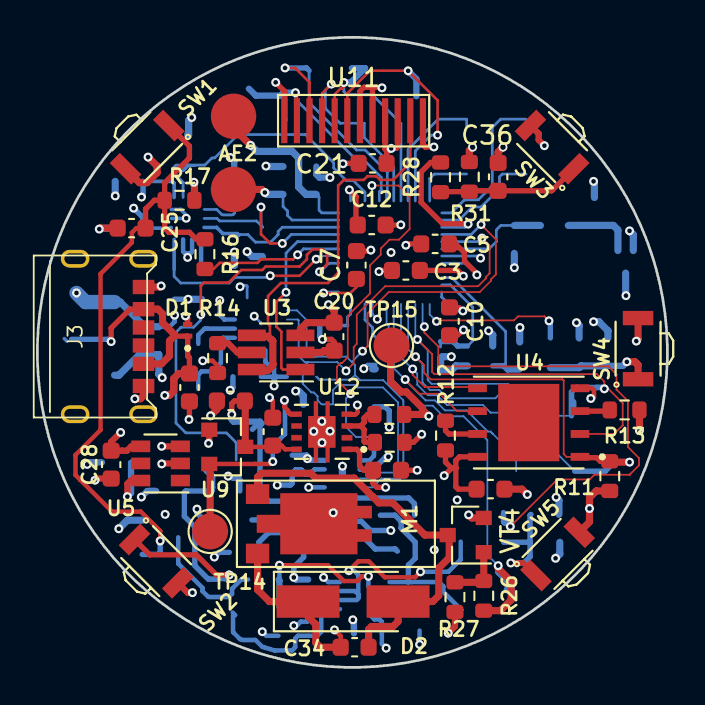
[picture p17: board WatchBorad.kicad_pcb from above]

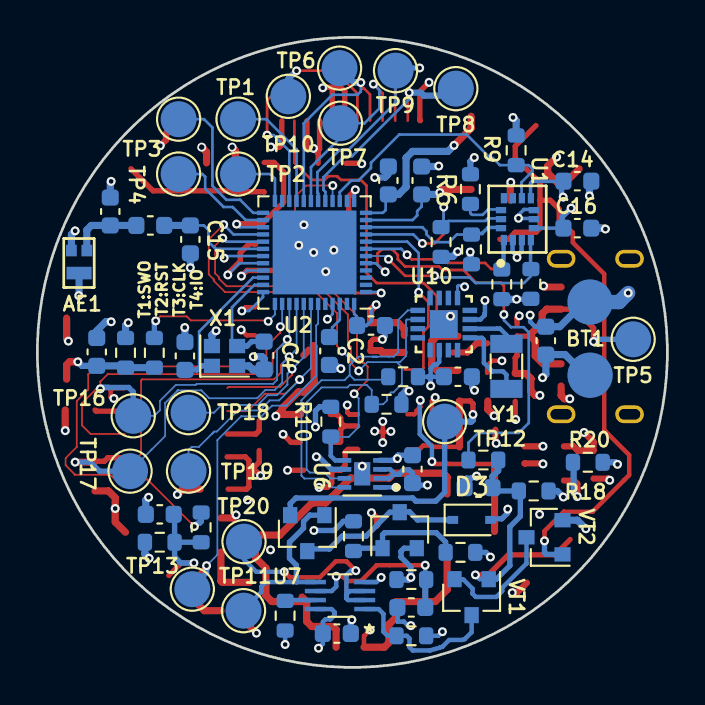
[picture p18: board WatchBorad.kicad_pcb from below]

Board: 4 copper layers, 35.0 x 35.0 mm, 119 parts (72 on the bottom side), 68 nets.

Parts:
3.9nH1: L; C_0603_1608Metric
AE1: Antenna_Chip; ANT2012LL13R2400A
AE2: Antenna_Loop; BatteryPads
BT1: Battery_Cell; BatteryPads
C1, C4: 10 pF; C_0603_1608Metric
C2, C8, C9, C20, C21, C23, C24, C28, C33, C40: 10 uF; C_0603_1608Metric
C3, C5: 100 pF; C_0603_1608Metric
C6, C7, C10, C12, C14, C16, C22, C25, C26, C27, C29, C32, C36, C37, C38: 100 nF; C_0603_1608Metric
C13, C15: 0.8 pF; C_0603_1608Metric
C18, C19: 130 pF; C_0603_1608Metric
C34: 100n X7R 16V; C_0603_1608Metric
D1: D_TVS; TVS_DFN1006
D2: 1A 20V; D_SMA_Handsoldering
D3: D; D_SOD-323
J3: TYPE-C-31-M-17
M1: Motor_DC; VibrationMorot4x4x11
R1, R2, R4, R5, R6, R7, R8, R9, R10, R11, R12, R13, R14, R17, R18, R20, R21, R22, R25, R27, R31, R32, R33: 10k; R_0603_1608Metric
R3: 330k; R_0603_1608Metric
R15, R16, R26, R28, R29, R30: 330; R_0603_1608Metric
R19: 220k; R_0603_1608Metric
R24: 1K; R_0603_1608Metric
R34: 10K; R_0603_1608Metric
SW1, SW2, SW3, SW4, SW5: SW_Push; SW_B3U-3000P
TP1, TP2, TP3, TP4, TP5, TP6, TP7, TP8, TP9, TP10, TP11, TP12, TP13, TP14, TP15, TP16, TP17, TP18, TP19, TP20: TestPoint; TestPoint_Pad_D2.0mm
U1: LSM6DSRTR; LSM6DSRTR_LGA-14L
U2: nRF52832-QFxx; QFN-48-1EP_6x6mm_Pitch0.4mm
U3: CAT4002ATD-GT3; SOT-23-6_Handsoldering
U4: MX25R1635F; W25Q128JVPIQ
U5: ME4055A; SOT-23-6
U6: MAX17048G+T10; MAX17048G
U7: SN74LVC2G74-EP_DCU_8; SN74LVC2G74
U9: MAX809S; SOT-23
U10: M41T62Q6F; QFN50P300X300X100-17N
U11: GC9A01; GC9A01_Extended_FPC
U12: TPS73501DRBR
VT1, VT2, VT4: SL2300; SOT-23
VT3, VT5: HX2301A; SOT-23
X1: Crystal_GND24_Small; Crystal_SMD_2016-4pin_2.0x1.6mm
Y1: Crystal_Small; Crystal_SMD_3215-2Pin_3.2x1.5mm

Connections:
+3V3: C9.1, C10.1, C12.1, C14.1, C16.1, C20.1, C21.1, C22.1, C34.1, C40.1, D2.1, M1.1, R3.1, R4.1, R5.1, R6.1, R7.1, R8.1, R9.1, R10.1, R11.1, R12.1, R13.1, SW3.2, SW4.2, SW5.2, TP15.1, U1.2, U1.3, U1.5, U1.8, U2.13, U2.36, U2.48, U3.3, U4.8, U11.3, U11.4, U12.1
+5V: C24.1, C28.1, D1.1, D3.2, J3.A9, J3.B9, R24.2, TP5.1, U5.4
+BATT: BT1.1, C6.1, C23.1, C27.1, C29.1, R1.1, R2.1, R21.2, R22.1, R25.1, SW1.2, SW2.2, U5.3, U6.2, U6.3, U7.8, U10.14, VT3.2
/DCDC&PB/DCDC_ENABLE: TP14.1, U9.2, U12.5
/DCDC&PB/DCDC_VIN: C32.1, C33.1, TP12.1, U9.3, U12.8, VT5.2
/DCDC&PB/Enable_motor: R26.2, TP13.1, U2.43
/DCDC&PB/LDO_RDIV: R3.2, R19.1, U12.3
/MCU/Backlight_EN_DIM: U2.8, U3.1
/MCU/DEC1: C7.1, U2.1
/MCU/DEC2: C5.1, U2.32
/MCU/DEC3: C3.1, U2.33
/MCU/DEC4: C2.1, U2.46
/MCU/DISP_CS: TP6.1, U2.20, U11.8
/MCU/DISP_DC: TP10.1, U2.22, U11.7
/MCU/DISP_RESET: TP8.1, U2.17, U11.11
/MCU/DISP_SCLK: TP7.1, U2.19, U11.9
/MCU/DISP_SDA: TP9.1, U2.18, U11.10
/MCU/FG_OD_ALRT_N: R10.2, U2.16, U6.5
/MCU/FLASH_CS: R11.2, TP17.1, U2.40, U4.1
/MCU/FLASH_MISO: TP16.1, U2.39, U4.2
/MCU/FLASH_MOSI: TP18.1, U2.41, U4.5
/MCU/FLASH_SCK: TP19.1, U2.42, U4.6
/MCU/I2C_SCL: R5.2, U1.13, U2.9
/MCU/I2C_SDA: R4.2, U1.14, U2.10
/MCU/LEDK: U3.4, U3.6, U11.2
/MCU/MPU_INT_1: R8.2, U1.4, U2.6
/MCU/MPU_INT_2: R9.2, U1.9, U2.15
/MCU/NC_PU: R6.2, U1.12
/MCU/NFC1: AE2.1, C19.1, U2.11
/MCU/NFC2: AE2.2, C18.1, U2.12
/MCU/PB_1_MCU: R15.2, U2.5
/MCU/PB_2_MCU: R16.2, U2.7
/MCU/PB_3_MCU: R28.2, U2.27
/MCU/PB_4_MCU: R29.2, U2.37
/MCU/PB_5_MCU: R30.2, U2.38
/MCU/SCL_FG: R1.2, U2.29, U6.7, U10.10
/MCU/SDA_FG: R2.2, U2.28, U6.8, U10.9
/MCU/SWD_RESET: TP2.1, U2.24
/MCU/SWD_SWDCLK: TP3.1, U2.25
/MCU/SWD_SWDIO: TP4.1, U2.26
/MCU/SWD_SWO: TP1.1, U2.21
/MCU/XC1: C1.1, U2.34, X1.1
/MCU/XC2: C4.1, U2.35, X1.3
/PSU_logic/PWR_SW_EN_N: TP11.1, U7.5, VT5.1
/PSU_logic/XI_RTC: U10.1, Y1.2
/PSU_logic/XO_RTC: U10.2, Y1.1
GND: AE1.2, BT1.2, C1.2, C2.2, C3.2, C4.2, C5.2, C6.2, C7.2, C8.2, C9.2, C10.2, C12.2, C13.2, C14.2, C15.2, C16.2, C18.2, C19.2, C20.2, C21.2, C22.2, C23.2, C24.2, C25.2, C26.2, C27.2, C28.2, C29.2, C32.2, C33.2, C36.2, C37.2, C38.2, C40.2, D1.2, J3.1, J3.A12, J3.B12, M1.CASE, R14.2, R17.1, R18.1, R19.2, R20.2, R27.2, R31.2, R32.2, R33.2, R34.2, U1.6, U1.7, U2.31, U2.45, U2.49, U3.2, U4.4, U5.2, U6.1, U6.4, U6.6, U6.9, U7.4, U9.1, U10.3, U10.5, U10.17, U11.1, U11.5, U11.6, U11.12, U12.4, U12.9, VT2.2, VT4.2, X1.2, X1.4
unnamed: 3.9nH1.1, AE1.1, C13.1
unnamed: 3.9nH1.2, C15.1, U2.30
unnamed: C8.1, R21.1, U7.6
unnamed: C25.1, R16.1, R17.2, SW1.1, VT2.1
unnamed: C26.1, R15.1, R18.2, SW2.1, VT1.1
unnamed: C34.2, D2.2, M1.2, VT4.3
unnamed: C36.1, R28.1, R31.1, SW3.1
unnamed: C37.1, R29.1, R32.1, SW4.1
unnamed: C38.1, R30.1, R33.1, SW5.1
unnamed: D3.1, VT3.3, VT5.3
unnamed: R7.2, U1.1
unnamed: R12.2, U4.7
unnamed: R13.2, U4.3
unnamed: R14.1, U3.5
unnamed: R20.1, U5.6
unnamed: R22.2, U7.1, VT1.3
unnamed: R24.1, R34.1, VT3.1
unnamed: R25.2, U7.7
unnamed: R26.1, R27.1, VT4.1
unnamed: TP20.1, U7.2, U7.3
unnamed: VT1.2, VT2.3

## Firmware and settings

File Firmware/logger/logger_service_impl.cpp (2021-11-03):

#include "inc/logger/logger_service.hpp"

#include "utils/CallbackConnector.hpp"

#include <atomic>
#include <type_traits>

#if defined(LoggerUart)
#include "app_error.h"
#include "app_uart.h"
#include "boards.h"
#include "bsp.h"
#include "nrf.h"
#elif defined(LoggerSwo)
#include "app_error.h"
#include "app_uart.h"
#include "boards.h"
#include "bsp.h"
#include "nrf.h"
#elif defined(LoggerSegger)
#include "SEGGER_RTT.h"
#elif defined(LoggerDesktop)
#include <cstdio>
#include <fmt/core.h>
#include <fmt/color.h>
#if defined USE_MSVC_DEBUG_OUT
#include <Windows.h>
#endif

#endif

namespace
{
std::string_view CaretReset = "\r\n";
}

#if defined(LoggerUart)

class Logger::LoggerImpl
{

public:
    LoggerImpl() noexcept
    {
        initLogInterface();
    }

    void logString(std::string_view _toLog) const noexcept
    {
        for (const auto ch : _toLog)
            app_uart_put(static_cast<std::uint8_t>(ch));
    }

private:
    void initLogInterface() noexcept
    {
        std::uint32_t errorCode{};

        const app_uart_comm_params_t appUartParams = {
            RX_PIN_NUMBER,
            TX_PIN_NUMBER,
            RTS_PIN_NUMBER,
            CTS_PIN_NUMBER,
            APP_UART_FLOW_CONTROL_DISABLED,
            false,
            UART_BAUDRATE_BAUDRATE_Baud115200};

        auto uartEventCallback = cbc::obtain_connector(
            [this](app_uart_evt_t* _pEvent) { return uartEventHandler(_pEvent); });

        APP_UART_FIFO_INIT(
            &appUartParams, RxSize, TxSize, uartEventCallback, APP_IRQ_PRIORITY_LOWEST, errorCode);

        APP_ERROR_CHECK(errorCode);
    }

private:
    static constexpr std::uint16_t TxSize = 256;    /**< UART TX buffer size. */
    static constexpr std::uint16_t RxSize = TxSize; /**< UART RX buffer size. */
    static constexpr std::uint8_t TestDataBytes =
        15; /**< max number of test bytes to be used for tx and rx. */

    void uartEventHandler(app_uart_evt_t* _pEvent) noexcept
    {
        if (_pEvent->evt_type == APP_UART_COMMUNICATION_ERROR)
        {
            APP_ERROR_HANDLER(_pEvent->data.error_communication);
        }
        else if (_pEvent->evt_type == APP_UART_FIFO_ERROR)
        {
            APP_ERROR_HANDLER(_pEvent->data.error_code);
        }
    }
};
#endif

#if defined(LoggerSwo)
class Logger::LoggerImpl
{

public:
    LoggerImpl() noexcept
    {
        initLogInterface();
    }

public:
    void logString(std::string_view _toLog) const noexcept
    {
        for (const auto ch : _toLog)
            ITM_SendChar(ch);
    }

private:
    void initLogInterface() noexcept
    {
        NRF_CLOCK->TRACECONFIG =
            (NRF_CLOCK->TRACECONFIG & ~CLOCK_TRACECONFIG_TRACEPORTSPEED_Msk) |
            (CLOCK_TRACECONFIG_TRACEPORTSPEED_4MHz << CLOCK_TRACECONFIG_TRACEPORTSPEED_Pos);

        ITM->TCR |= 1;
        ITM->TER |= 1;
    }
};
#endif

#if defined(LoggerSegger)
class Logger::LoggerImpl
{

public:
    void logString(std::string_view _toLog) const noexcept
    {
        SEGGER_RTT_WriteString(0, _toLog.data());
    }
};
#endif

#if defined(LoggerDesktop)
class Logger::LoggerImpl
{

public:
    void logString(std::string_view _toLog) const noexcept
    {
        fmt::print(fg(fmt::color::steel_blue),"{}",_toLog.data());
#if defined USE_MSVC_DEBUG_OUT
        OutputDebugString(_toLog.data());
#endif
    }
};
#endif

Logger::Logger() noexcept = default;

Logger::~Logger() = default;

Logger& Logger::Instance() noexcept
{
    static Logger intance;
    return intance;
}

void Logger::logDebugEndl(std::string_view _toLog) noexcept
{
    m_pLoggerImpl->logString(_toLog);
    m_pLoggerImpl->logString(CaretReset);
}

void Logger::logDebug(std::string_view _toLog) noexcept
{
    m_pLoggerImpl->logString(_toLog);
}

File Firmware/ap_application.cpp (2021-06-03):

#include "ap_application.hpp"

#include "ih/drivers/ih_ble_service_factory.hpp"
#include "ih/drivers/ih_ible_softdevice.hpp"

#include "board/watchboard.hpp"
#include "i2c/i2c_test.hpp"

#include "graphics/gs_event_dispatcher.hpp"
#include "graphics/gs_lvgl_service.hpp"
#include "graphics/ih/gs_imain_window.hpp"

#include <utils/CoroUtils.hpp>
#include <utils/SimpleSignal.hpp>

#include <logger/logger_service.hpp>

#include <optional>

namespace EventConvert
{
Graphics::Events::TButtonsEvents toButtonEvent(Buttons::ButtonState _buttonToConvert)
{
    switch (_buttonToConvert)
    {
    case Buttons::ButtonState::kButtonUp:
        return Graphics::Events::TButtonsEvents::ButtonReleased;
    case Buttons::ButtonState::kButtonDown:
        return Graphics::Events::TButtonsEvents::ButtonPressed;
    case Buttons::ButtonState::kButtonClick:
        return Graphics::Events::TButtonsEvents::ButtonClicked;
    case Buttons::ButtonState::kButtonDblClick:
        return Graphics::Events::TButtonsEvents::ButtonDblClick;
    case Buttons::ButtonState::kButtonLongPress:
        return Graphics::Events::TButtonsEvents::ButtonLongClick;
    default:
        assert(false);
        return Graphics::Events::TButtonsEvents::ButtonPressed;
    }
}
} // namespace EventConvert

Application::Application() noexcept
{
    initBoard();
    initPeripheral();
    initServices();
    initGraphicsStack();
    initBleStack();
    connectBoardSpecificEvents();
}

Application::~Application() noexcept = default;

void Application::initBoard() noexcept
{
    m_pBoardImpl = WatchBoard::createBoard();
}

void Application::initServices() noexcept
{
    m_fakeServiceProvider = ServiceProviders::getFakeServiceCreator();
    m_batteryLevelService = m_fakeServiceProvider->getBatteryService();
    m_heartrateService = m_fakeServiceProvider->getHeartrateService();
    m_dateTimeService = m_fakeServiceProvider->getDateTimeService();
}

void Application::initPeripheral() noexcept
{
}

void Application::initBleStack() noexcept
{

    m_bleStackKeeper =
        std::move(Ble::Stack::createSoftDevice(Ble::ServiceFactory::getBleServiceFactory()));

    if (!m_bleStackKeeper)
        return;

    auto& batteryServiceBle = m_bleStackKeeper->getBatteryService();

    m_batteryLevelService->onBatteryLevelChangedSig.connect(
        [&batteryServiceBle](std::uint8_t _newBatteryValue) {
            batteryServiceBle.onBatteryLevelChanged(_newBatteryValue);
        });

    auto& pMainWindow = m_graphicsService->getMainWindow();
    m_bleStackKeeper->onConnected.connect([&pMainWindow] {
        pMainWindow.getEventDispatcher().postEvent(
            {Graphics::Events::EventGroup::BleDevice,
             Graphics::Events::TBleClientEvents::DeviceConnected,
             std::nullopt});
    });

    m_bleStackKeeper->onDisconnected.connect([&pMainWindow] {
        pMainWindow.getEventDispatcher().postEvent(
            {Graphics::Events::EventGroup::BleDevice,
             Graphics::Events::TBleClientEvents::DeviceDisconnected,
             std::nullopt});
    });

    auto& dateTimeService = m_bleStackKeeper->getDateTimeService();
    dateTimeService.onDateTimeDiscovered.connect([&pMainWindow](const TimeWrapper& _newBleTime) {
        pMainWindow.getEventDispatcher().postEvent(
            {Graphics::Events::EventGroup::DateTime,
             Graphics::Events::TDateTimeEvents::DateTimeChanged,
             _newBleTime});
    });
}

void Application::initGraphicsStack() noexcept
{
    m_graphicsService = Graphics::createGraphicsService();

    auto& pMainWindow = m_graphicsService->getMainWindow();

    m_batteryLevelService->onBatteryLevelChangedSig.connect(
        [&pMainWindow](std::uint8_t _newBatteryValue) {
            pMainWindow.getEventDispatcher().postEvent(
                {Graphics::Events::EventGroup::Battery,
                 Graphics::Events::TBatteryEvents::BatteryLevelChanged,
                 _newBatteryValue});
        });

    m_dateTimeService->onDateTimeChanged.connect([&pMainWindow](const TimeWrapper& _newTime) {
        pMainWindow.getEventDispatcher().postEvent(
            {Graphics::Events::EventGroup::DateTime,
             Graphics::Events::TDateTimeEvents::DateTimeChanged,
             _newTime});
    });
}

void Application::connectBoardSpecificEvents() noexcept
{
    auto& pMainWindow = m_graphicsService->getMainWindow();

    m_pBoardImpl->getButtonsDriver()->onButtonEvent.connect(
        [&pMainWindow](Buttons::ButtonEvent _buttonEvent) {
            Graphics::Events::HardwareButtonId graphicsButton{
                Graphics::Events::enumConvert<Graphics::Events::HardwareButtonId>(
                    _buttonEvent.buttonId)};

            pMainWindow.getEventDispatcher().postEvent(
                {Graphics::Events::EventGroup::Buttons,
                 EventConvert::toButtonEvent(_buttonEvent.buttonEvent),
                 graphicsButton});
        });
}

void Application::runApplicationLoop() noexcept
{
    I2C::scanI2CSensors();

    m_batteryLevelService->startBatteryMeasure();
    m_dateTimeService->launchService();
    m_pBoardImpl->ledToggle();

    while (true)
    {
        CoroUtils::CoroQueueMainLoop::GetInstance().processQueue();
        Simple::Lib::ExecuteLaterPool::Instance().processQueue();
        m_graphicsService->executeGlTask();
    }
}

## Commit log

2019-10-05 Added draft of schematic. Added cmake-build
    [WatchBorad.kicad_pcb, WatchBorad.sch, _saved_WatchBorad.sch]
2019-10-06 Launched onboard UART peripheral
    [WatchBorad.sch, _saved_WatchBorad.sch]
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2019-10-14 Schematics changes - routed display part
    [AB2_TSSOP20_WINGS3D.stl, SOIC10-150-50.STEP, SOIC12-150-50.STEP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]
2019-10-14 Moved display part nearly to E73
    [WatchBorad.kicad_pcb]
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2019-10-19 Added Framebuffer keeper [SPI REFACTORING]
    [BU6655NUX-TR.STEP, WatchBorad.kicad_pcb, WatchBorad.sch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]
2019-10-19 Fixed display drawing[SPI REFACTORING]
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2019-10-19 Fixed colors displaying [SPI REFACTORING]
2019-10-19 Fixed bug in counter for SPI buffer fill [SPI REFACTORING]
2019-10-22 Started work on BLE driver [BLE, UNTESTED]
    [WatchBorad.sch]
2019-10-26 Moved footprints and symbol libraries to KICAD_LIBRARIES_ROOT
    [AB2_TSSOP20_WINGS3D.stl, BU6655NUX-TR.STEP, SOIC10-150-50.STEP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]
2019-10-26 Draft of board route [PCB Routing]
    [WatchBorad.kicad_pcb, WatchBorad.sch]
2019-10-26 Updated board summary. Added borders and names for several schematic parts
    [WatchBorad.kicad_pcb, WatchBorad.sch]
2019-10-26 Project version is bumped by KiCad
    [WatchBorad.kicad_pcb]
2019-10-27 Added connectors for top-board
    [WatchBorad.kicad_pcb, WatchBorad.sch]
2019-10-27 Added connectors for top-board-schematic
    [WatchBorad.sch]
2019-10-28 Revert "Added connectors for top-board-schematic"
    This reverts commit 6170a2acdf532fd042b1f8efa63f942ad96a6e4b.
    [WatchBorad.sch]
2019-10-28 Draft of PCB routing [PCB]
    [WatchBorad.kicad_pcb, WatchBorad.sch]
2019-10-31 Routed MAX30102, routed Buttons [PCB]
    [WatchBorad.kicad_pcb, WatchBorad.sch]
2019-11-02 Moved tisplay on the top of the board[PCB]
    [WatchBorad.kicad_pcb, WatchBorad.sch]
2019-11-02 Added P_19 as button SW4
    [WatchBorad.kicad_pcb, WatchBorad.sch]
2019-11-02 Fixed routing for display connector [PCB]
    [WatchBorad.kicad_pcb, WatchBorad.sch]
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2019-11-02 Increased capacitors for LDO 3V3 [PCB]
    [WatchBorad.kicad_pcb, WatchBorad.sch]
2019-11-02 Added screenshots & gerbers for v1.0 release
    [WatchBorad-B.Cu.gbr, WatchBorad-B.Mask.gbr, WatchBorad-B.Paste.gbr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]
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2019-11-20 Fixed BLE stack init. Now device visible while advertising state. Connectable too.[BLE]
    [logger_service_impl.cpp]
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2019-11-24 Fixed battery service timer [BLE]
    [ap_application.cpp]
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2019-12-21 Fixed lvgl displaying draft version [LVGL]
    [ap_application.cpp]
2019-12-22 Fixed random display freezing
    [ap_application.cpp]
2019-12-25 Fixed graphics layer hanging [LVGL]
    [ap_application.cpp]
2019-12-28 Added preloader. Fixed issue in st7789v driver in chunked transaction [LVGL][DISPLAY]
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2020-01-21 Fixed st7789v driver drawing [DISPLAY]
2020-01-22 Fixed several codacy warnings [GENERAL]
    [logger_service_impl.cpp]
2020-01-22 Fixed codacy wanring in battery service
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2020-02-10 Eventually fixed display driver drawing [DISPLAY]
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2020-03-03 Chunked transactions fix for ST7789 driver [DISPLAY]
2020-03-15 Fixed native build. Added ugly pages demo switching [LVGL]
2020-03-25 Revert enumConvert, produces error in VS2019 build [GENERAL]
    This reverts commit 3d1bb6d06bee8107f2c4517d167d0794c946898a.
    [ap_application.cpp]
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2020-04-11 Fixed battery widget initial drawing [LVGL][BATTERY]
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2020-04-12 Added hierarchical sheet with vibration motor circuit
    [VibrationMotor.sch, WatchBorad.sch]
2020-04-20 Fixed displaying for pages switch after changing theme [GENERAL][LVGL]
2020-04-20 Fixed battery and page view displaying logic [GENERAL][LVGL]
2020-04-21 Added PowerSupply and MCU hierarchical sheets.
    [MCU.sch, PowerSupply.sch, VibrationMotor.sch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]
2020-04-27 Fixed reordering warning in Battery Widget [GENERAL]
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2020-04-29 Revert "Added FastPIMPL for battery service [GENERAL]"
    This reverts commit 38d4b7d2e4562099066947991ad8ba1f65ada49b.
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2020-05-03 Fixed Windows build [GENERAL]
    [ap_application.cpp]
2020-05-03 Fixed codacy c-tor initialization warning [GENERAL][SPI]
2020-05-06 Temponary disabled pages switching and theme changing for profiling memory consumption while theme changing(seems as memory leak in lv_style_implementation) [LVGL_7.0]
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2020-05-16 CI setup for gcc and MSVC [CI][GENERAL] (#13)
    * Added fetching latest arm-gcc-none-eabi
    * Added fetching NRF52SDK
    * Added missed mkdir for SDK files
    * Changed slashes for SDK path
    * Added quotes for SDK path
    * Added download files action
    * Added download files action
    * Added download files action
    * Added download files action
    * Added download files action
    * Added download files action
    * Added download files action
    * Added download files action
    * Added download files action
    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
2020-05-19 Added BleSoftdevice factory, service factory. Fixed warnings in pages handlers [GENERAL][BLE]
    [ap_application.cpp]
2020-05-25 Corrected Board's butons pin numbers [BUTTONS]
2020-05-27 Added Meta::Unuse var. Minor fixes for reordering warnings. Added connection for datetime events[GENERAL]
    [ap_application.cpp]
2020-05-29 Fixed mainwindow build [GENERAL]
    [ap_application.cpp]
2020-05-30 Added on/off circuit for PON and added other changes
    [MCU.sch, PowerSupply.sch, PushButtons.sch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]
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2020-06-11 Particial fixed build for SPI-wrapper [CMAKE]
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2020-06-12 Fixed gpio build [CMAKE]
    [gpio_pin.cpp]
2020-06-13 Added platform delay, fixed build for libwatchdisplay [CMAKE]
    [gpio_pin.cpp]
2020-06-13 Refactoring of include paths in project. Fixed build for graphics target
    [gpio_pin.cpp]
2020-06-16 Fixed firmware launchning [CMAKE]
    [gpio_pin.cpp]
2020-06-16 Fixed I2C example start [CMAKE]
2020-06-16 Fixed includes in ap_application [CMAKE]
    [ap_application.cpp]
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2020-06-16 Almost fixed Windows build[CMAKE]
    [gpio_pin.cpp]
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2020-06-25 Fixed device specific issues [GPIO][DISPLAY][BLE_WIDGET]
    [gpio_pin.cpp]
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2020-06-26 Fixed GPIO calls logging [SIMULATOR]
    [gpio_pin.cpp]
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2020-07-30 Fixed driver for GC9A01 [DISPLAY]
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2020-08-01 Added firts failed test for buttons module [BUTTONS]
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2020-08-06 Fixed linux build [GCC][BUTTONS]
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2020-08-06 Fixed long button click test [TETS]
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2020-08-14 Fixed hardware backend for Nordic buttons timer [BUTTONS]
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2020-08-16 Added main window event handler. Fixed tests [MAIN_WINDOW][TEST]
    [ap_application.cpp]
2020-08-17 Buttons fix for Nordic hardware [BUTTONS]
2020-08-17 Added failing for sequence of the same button clicks [BUTTONS]
2020-08-18 Added failing tests for doubleclicks sequence and short click after long click detection [BUTTONS]
2020-08-19 Fixed buttons driver implementation [BUTTONS]
2020-08-19 Fixed buttons driver Win32API implementation [BUTTONS]
2020-08-19 Fixed timer hardware backend for Buttons [BUTTONS]
2020-08-20 Fixed timeout for click detection for Win32 backend [BUTTONS]
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2020-09-03 Fixed Jededc ID & Device ID reading #17 [SPI_FLASH]
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2020-09-12 Fixed SPI build [SPI]
2020-09-21 Revert "Fixed SPI build [SPI]"
    This reverts commit 38c1c191f441c5179f46610426a70fe7130e4409.
2020-09-21 Revert "Draft pimpl & untemplating [SPI]"
    This reverts commit 81c5cf43ea64ed34e9da1086fb5bf18ebac3cae3.
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2020-09-28 Probably fixed coroutine led blinking [CORO]
    [ap_application.cpp]
2020-09-29 Fixed nullptr dereferencing in timer callback [BOARD]
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2020-10-08 Fixed MSVC build with coroutines for spi on display [CORO]
    [gpio_pin.cpp]
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2020-10-20 Corrected SPI stub [CORO]
2020-10-22 Corrected SPI coroutine impl with using std::array [CORO]
2020-10-23 Corrected SPI coroutine impl with Awaitable fixes [CORO]
2020-10-27 Fixed SPI transactions [CORO]
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2020-11-23 Display is replaced, now it has single power supply. One PSU is removed. Circuit PB is modified.
    [DCDC&PB.sch, DCDC_FG_BCH_PB.sch, MCU.sch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]
2020-12-06 PBs are modified to one logic. Some minot changes
    [DCDC&PB.sch, MCU.sch, PSU_logic.sch]
2021-01-06 Moved SDL dependency to Conan package manager (#20)
    * Local draft for mocked SPI [SPI][CORO]
    * Removed SDL package from lv_drives dependency [PACKAGE]
    * Added SDL package with Conan [PACKAGE]
    * Updated CI for supporting Conan [PACKAGE]
    * CI fix[PACKAGE]
    * CI fix[PACKAGE]
    * CI fix[PACKAGE]
    * CI fix[PACKAGE]
    * CI fix[PACKAGE]
    * CI fix[PACKAGE]
    * CI fix[PACKAGE]
    * CI fix[PACKAGE]
    * CI fix[PACKAGE]
    * CI fix[PACKAGE]
    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
2021-01-19 Added caching for ARM-GCC builds (#21)
    * Changed folder for GCC toolchain cache[CI]
    * Added caching to gcc build
    * Attempted to fix build [CI]
    * Attempted to check cache [CI]
2021-04-02 Fixed styles' selectors. Fixed driver config[LVGL]
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2021-04-19 Fixed command-to-send size [SPI][CORO]
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2021-05-05 Added value-driven wuite for SPI. Fixed templated driver implementation [SPI][CORO]
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2021-05-05 Just for testing fixed spi_wrapper_async[SPI][CORO]
2021-05-05 Fixed GPIO namespace include[GPIO]
    [gpio_pin.cpp]
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2021-05-06 Fixed SPI Instance for display [SPI]
2021-05-21 Fixed Spi handle initialization [CORO][TEMPLATED]
2021-05-25 Fixed templated display driver [CORO]
2021-05-26 Attempted to fix build with default driver [CORO]
2021-05-26 Fixed ARM target build [BUILD]
2021-05-26 Fixed Default driver build [GC_DISPLAY]
2021-05-26 Fixed Default driver build ; [GC_DISPLAY]
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2021-06-01 Fixed build ARM
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2021-06-02 Fixed driver implementation [CORO]
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2021-06-10 Fixed SPI implementation [CORO]
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2021-06-14 Fixed ARM build [BUILD]
2021-06-17 Fixed LCSC schematic link :Schematic [SCHEMATIC]
    [DCDC&PB.sch, MCU.sch, PSU_logic.sch]
2021-06-17 Added missed parts list [SCHEMATIC]
2021-06-19 Added footpring for GC9A01 display. Fixed display lines(FMARK->DC)
    [DCDC&PB.sch, MCU.sch]
2021-06-19 Fixed components references for 0603 resistors and capacitors[SCHEMATIC]
    [DCDC&PB.sch, MCU.sch, PSU_logic.sch]
2021-06-19 Corrected missed footprints. Added buttons' positions
    [WatchBorad.kicad_pcb]
2021-06-19 Updated schematic. Draft of components position
    [WatchBorad.kicad_pcb]
2021-06-19 Updated 0603 components from hand-solder version to fabrical
    [DCDC&PB.sch, MCU.sch, PSU_logic.sch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]
2021-06-19 Added winbond flash instead of previous one
    [MCU.sch, WatchBorad.kicad_pcb]
2021-06-20 Added more routings for components.Moved MCU to the top layer. Added 4-layer board setup
    [MCU.sch, PSU_logic.sch, WatchBorad.kicad_pcb]
2021-06-20 Moved crystal to the top layer. Fixed SVD interface
    [WatchBorad.kicad_pcb]
2021-06-20 Keepout fix for the antenna shape
    [WatchBorad.kicad_pcb]
2021-06-20 Updated parts list accroding to the Ruslan fixes
    [DCDC&PB.sch, PSU_logic.sch, WatchBorad.kicad_pcb]
2021-06-20 Added Type-C and Vibro motor 3D models
    [WatchBorad.kicad_pcb]
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2021-06-20 Fixed Type-C position. Added 3Dmodel for winbond
    [MCU.sch, WatchBorad.kicad_pcb]
2021-06-23 Added 3D model for diode
    [WatchBorad.kicad_pcb]
2021-06-29 Updated & fixed missed SCH parts list
    [DCDC&PB.sch, MCU.sch, PSU_logic.sch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]
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2021-06-29 Fixed buttons layout. Added layout draft for the display testpoints [SCHEMATIC]
    [DCDC&PB.sch, MCU.sch, PSU_logic.sch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]
2021-07-03 Added missed footprints
    [MCU.sch, PSU_logic.sch, WatchBorad.kicad_pcb]
2021-07-03 Almost placed everything onto 2 layers
    [WatchBorad.kicad_pcb]
2021-07-03 Fixed buttons position
    [MCU.sch, WatchBorad.kicad_pcb]
2021-07-03 Fixed 3D models paths
    [WatchBorad.kicad_pcb]
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2021-07-03 Fixed DRC warnings
    [WatchBorad.kicad_pcb]
2021-07-03 Fixed 3D models
    [WatchBorad.kicad_pcb]
2021-07-03 Fixed layout for display & SWD interface
    [WatchBorad.kicad_pcb]
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2021-07-06 Fixed vibro position
    [WatchBorad.kicad_pcb]
2021-07-06 Updated footprints to the actual one
    [WatchBorad.kicad_pcb]
2021-07-06 Fixed board's proposals. Fixed testpoints' footprint. Fixed DRC violations. Added +5V testpoint
    [DCDC&PB.sch, MCU.sch, PSU_logic.sch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]
2021-07-06 Added route for crystal
    [WatchBorad.kicad_pcb]
2021-07-06 Added route for display testpoints
    [WatchBorad.kicad_pcb]
2021-07-06 Added route for SPI-FLASH
    [MCU.sch, WatchBorad.kicad_pcb]
2021-07-06 Added routing for power plane
    [MCU.sch, WatchBorad.kicad_pcb]
2021-07-06 Added testpoints for SPI-FLASH
    [MCU.sch, WatchBorad.kicad_pcb]
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2021-07-07 Added cooper region for GND layer
    [WatchBorad.kicad_pcb]
2021-07-07 Added display's GND via
    [WatchBorad.kicad_pcb]
2021-07-08 Added GND plane routing
    [WatchBorad.kicad_pcb]
2021-07-08 Added PCB route for GND vias
    [WatchBorad.kicad_pcb]
2021-10-12 Fixed build under desktop linux platform
    [gpio_pin.cpp]
2021-10-12 Attempted to fixup CI build for Windows and Linux
    [gpio_pin.cpp]
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2021-10-17 Added RTC to the schematic and PCB lists [PCB]
    [MCU.sch, WatchBorad.kicad_pcb]
2021-10-17 Added pull-up resistors for I2C bus. Refactored PCB for the Front layer
    [MCU.sch, WatchBorad.kicad_pcb]
2021-10-18 Refactored PCB structure. Removed RTC crystal from Nordic MCU clocking
    [MCU.sch, WatchBorad.kicad_pcb]
2021-10-18 Added routing for the power supply. Fixed schematic issue with the charger
    [PSU_logic.sch, WatchBorad.kicad_pcb]
2021-10-19 Added routing for the display backlight, refactored DC-DC routing
    [WatchBorad.kicad_pcb]
2021-10-19 Removed MAX30102 from schemtic and PCB
    [MCU.sch, WatchBorad.kicad_pcb]
2021-10-19 Added decoupling capacitors routing. Fixed area around MCU
    [WatchBorad.kicad_pcb]
2021-10-19 Rerouted MPU_INT area [PCB]
    [WatchBorad.kicad_pcb]
2021-10-19 Fixed DRC unrouted nets warnings
    [WatchBorad.kicad_pcb]
2021-10-19 Completed draft PCB layout routing
    [MCU.sch, WatchBorad.kicad_pcb]
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2021-10-23 Removed gerbers from repo
    [WatchBorad-B.Cu.gbr, WatchBorad-B.Mask.gbr, WatchBorad-B.Paste.gbr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]
2021-10-23 Added new DCDC and radio antenna from Rulepas [SCHECMATIC]
    [DCDC&PB.sch, MCU.sch, PSU_logic.sch]
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2021-10-24 Added LDO instead of DC-DC. Added board routing accroding to the new peripheral changes [SCHEMATIC]
    [DCDC&PB.sch, WatchBorad.kicad_pcb]
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2021-10-25 Fixed PCB Layout for LDO vias [PCB]
    [WatchBorad.kicad_pcb]
2021-10-25 Replaced power traces with the polygons [PCB]
    [WatchBorad.kicad_pcb]
2021-10-25 Fixed filled power zones [PCB]
    [WatchBorad.kicad_pcb]
2021-10-25 Added NFC antenna pads on the PCB [NFC][PCB]
    [MCU.sch, WatchBorad.kicad_pcb]
2021-10-26 Updated solder mask clearance for the project [PCB]
2021-10-26 Corrected polygon fills for the power layer
    [WatchBorad.kicad_pcb]
2021-10-26 Fixed antenna layout routing. Fixed 3D model paths [PCB]
    [WatchBorad.kicad_pcb]
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2021-10-27 Fixed antenna routing according to the datasheet [PCB]
    [WatchBorad.kicad_pcb]
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2021-10-27 Fixed capacitors near the fuel gauge [PCB]
    [WatchBorad.kicad_pcb]
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2021-10-27 Refactored routing near the LDO(capacitors + resistors) [PCB][SCHEMATIC]
    [WatchBorad.kicad_pcb]
2021-10-27 Removed away the trace between Battery input and the battery charger [PCB]
    [WatchBorad.kicad_pcb]
2021-10-27 Fixed +5V traces. Moved them to the internal layer [PCB]
    [WatchBorad.kicad_pcb]
2021-10-28 Added missed components to the symbol lists [SCHEMATIC]
    [DCDC&PB.sch, MCU.sch, PSU_logic.sch]
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2021-10-28 Added missed resistors to the lcsc [SCHEMATIC][BOM]
    [DCDC&PB.sch, MCU.sch, PSU_logic.sch]
2021-10-28 Fixed PCB layout for GND pads near the buttons [PCB]
    [WatchBorad.kicad_pcb]
2021-10-30 Added D-trigger instead of the MAX switching chip
    [PSU_logic.sch, WatchBorad.kicad_pcb]
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2021-10-30 Fixed silkscreen appearance [PCB]
    [WatchBorad.kicad_pcb]
2021-10-31 Fixed D-trigger routing around the switching circuit [PCB]
    [PSU_logic.sch, WatchBorad.kicad_pcb]
2021-10-31 After draft-plot corrections [PCB]
    [WatchBorad.kicad_pcb]
2021-11-03 Moved GTest to conan instead of building a submodule (#31)
    * Removed gtest from submodules
    * Moved gtest to the conan packages
    * Removed gtest from submodules
    * Moved gtest to the conan packages
    * Attempted to fixup cmake build for visual studio [SIMULATOR]
    * Attempted to fixup cmake build for visual studio [SIMULATOR]
    * Removed default font from LVGL config
    * Revert "Removed default font from LVGL config"
    This reverts commit 4e84bbb35766a1f7b5d312761488f3d2e007ab43.
    * Fixed CMakeSettings.json
    * Attempted to fix crash on Windows
    * Removed cmake run action. Changed to a raw cmake call instead
    * Attempted to fixup workflow file
    * Removed FMTLIB headeronly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
    [logger_service_impl.cpp]
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2021-11-07 Fixed D3 footpint [SCHEMATIC][PCB]
    [PSU_logic.sch, WatchBorad.kicad_pcb]
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2021-11-08 Fixed crash which was reproducible under the ASAN builds on Windows platform (#36)
    * Added draft fixup of the application start
    * Attempted to force-building SDL2 package
    * Fixed SDL build with conan
    * Removed unnecessary calls to the tick_thread since SDL does this internally
    * Updated LVGL version for the project
    * Fixed crash under Windows platform [ASAN]
    * Fixed ram overflow for ARM.[LVGL]
2021-11-09 Fixed Transistor position in PSU_Logic POwer MUX [PCB] [SCHEMATIC]
    [PSU_logic.sch, WatchBorad.kicad_pcb]
2021-11-14 Fixed silkscreen on the bottom layer [PCB]
    [WatchBorad.kicad_pcb]
2021-11-15 Corrected display routing. Added correct version of the display connector
    [MCU.sch, WatchBorad.kicad_pcb]
2021-11-16 Fixed a few board issues. Removed extra power plane from the Battery connetion #38
    [WatchBorad.kicad_pcb]
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2021-11-17 Fixed accelerometer 3d model path [3D MODELS]
    [WatchBorad.kicad_pcb]
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2021-12-31 Added 3D models for D-trigger, LDO, Crystals [PCB]
    [WatchBorad.kicad_pcb]
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2023-03-27 [graphics] fixed automatic pages switch task

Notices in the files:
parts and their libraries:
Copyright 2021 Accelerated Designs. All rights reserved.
